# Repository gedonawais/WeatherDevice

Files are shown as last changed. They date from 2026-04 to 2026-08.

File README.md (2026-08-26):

# Weather Device - Raspberry Pi Zero 2W Setup Guide

This document explains how to set up the Raspberry Pi Zero 2W for the Weather Device project.

---

# 1. Install Raspberry Pi OS Lite (64 Bit) without Desktop

1. Download and install **Raspberry Pi OS Lite** using Raspberry Pi Imager.
2. Flash the OS to the SD card.
3. Before writing the image, configure:
   - Set username and password
   - Configure Wi-Fi (optional)

Boot the Raspberry Pi.

---

# 2. Configure Raspberry Pi

## 2.1 Enable Automatic Login

Open the Raspberry Pi configuration tool:

```bash
sudo raspi-config
```
Set System Date and Time and WLAN Country in the Localisation menu
Set Wireless LAN SSID and Password (for wifi)

Navigate to:
```
System Options
    → Auto Login
        → Console Autologin
```

Select console auto login.

This allows the Raspberry Pi to automatically log in after boot.

---

## 2.2 Disable sudo Password Requirement

Navigate to:
```
System Options
    → Admin Password
        → Disable
```

This allows scripts and services to execute sudo commands without requiring a password.

---

# 3. Configure Network

## 3.1 Connect to Wi-Fi

Open Raspberry Pi configuration:

```bash
sudo raspi-config
```

Navigate to:

```
System Options
    → Wireless LAN
```

Enter:

- Wi-Fi SSID
- Wi-Fi password

Reboot if required.

---

# 4. Install Required Software

## 4.1 Update Package List

Run:

```bash
sudo apt update
```

---

## 4.2 Install Git

Install Git:

```bash
sudo apt install git -y
```

Verify installation:

```bash
git --version
```

---

# 5. Download Weather Device Repository
If you wish to enable Wifi use the following commands

```bash
sudo systemctl enable NetworkManager.service
sudo systemctl start NetworkManager.service
sudo nmcli radio wifi on
```
Move to the home directory:

```bash
cd /home
```

Clone the repository:

```bash
sudo git clone <REPOSITORY_URL>
```

Example:

```bash
sudo git clone https://github.com/<username>/WeatherDevice.git
```

The project should now be available at:

```
/home/WeatherDevice
```

---

# 6. Configure Git Repository Permission

If Git shows a **"detected dubious ownership in repository"** error, run:

```bash
git config --global --add safe.directory /home/WeatherDevice
```

---

# 7. Deploy System Configuration

Run the configuration deployment script:

```bash
bash /home/WeatherDevice/Firmware/RPi/Installations/deploy_config.sh
```

This installs required system files, services, and configurations.

---

# 8. Restart Raspberry Pi

Reboot the device:

```bash
sudo reboot
```

Wait until the Raspberry Pi boots again.

---

# 9. Install Python Dependencies

Run the installation script:

```bash
bash /home/WeatherDevice/Firmware/RPi/Installations/install.sh
```

This installs all required libraries and dependencies.

---

# 10. Disable Wi-Fi (Optional)
Network Manager is already disabled so no need to run this
Disable Wi-Fi:

```bash
sudo nmcli radio wifi off
```

Check Wi-Fi status:

```bash
nmcli radio
```

---

# 11. Weather Service Management

## Start Weather Service

```bash
sudo systemctl start weather.service
```

---

## Enable Service at Boot

To automatically start the weather application after every reboot:

```bash
sudo systemctl enable weather.service
```

---

## Check Service Status

```bash
sudo systemctl status weather.service
```

---

## View Live Service Logs

To monitor real-time logs:

```bash
journalctl -u weather.service -f
```

---

## Restart Service if there are any issues in logs

After changing code:

```bash
sudo systemctl restart weather.service
```

---

# 12. Updating the Software

To update the Weather Device software:

```bash
sudo nmcli radio wifi on
cd /home/WeatherDevice
```

Download the latest changes:

```bash
sudo git pull
sudo nmcli radio wifi off
```

Restart the service:

```bash
sudo systemctl restart weather.service
```

---

# Setup Complete

The Raspberry Pi Zero 2W is now configured and ready to run the Weather Device application.

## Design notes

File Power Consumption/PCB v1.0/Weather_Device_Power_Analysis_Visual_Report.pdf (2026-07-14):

# Weather Device Power Analysis Report

Visual summary based on 24-hour measurements.

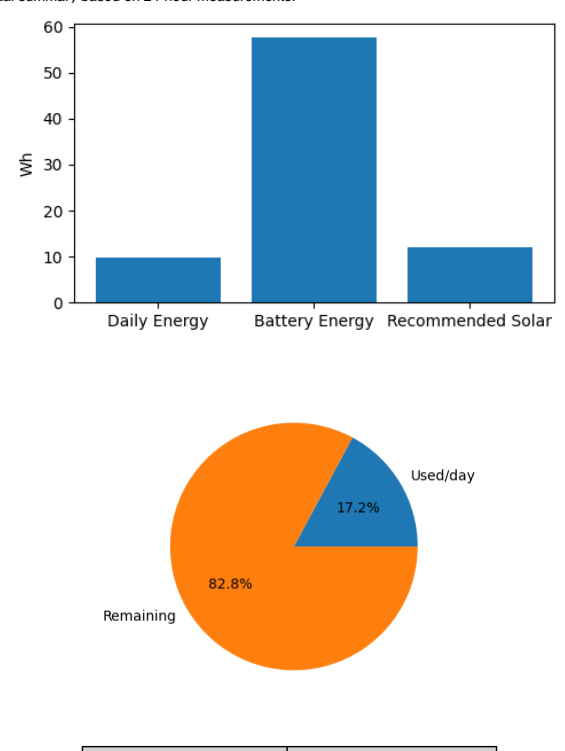
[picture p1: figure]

Metric | Value
Daily Energy | 9.896 Wh
Daily Charge | 842.3 mAh
Average Power | 0.412 W
Battery | 3S Li-ion 5200 mAh (57.7 Wh)
Runtime | ~5.8 days

Recommended Solar Harvest >=12 Wh/day

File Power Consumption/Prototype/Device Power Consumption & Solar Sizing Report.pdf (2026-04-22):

# Device Power Consumption & Solar Sizing Report (24h Analysis)

### 1. Daily Energy Consumption

Total: 7.613 Wh/day
Active: 7.333 Wh (~3.72 h) Sleep: 0.280 Wh (~20.26 h) Active dominates (~96.3% energy)

### 2. Power Profile

Active: ~1.97 W
Sleep: ~0.014 W (14 mW)

### 3. System Losses

Efficiency: 70%
Required: 10.9 Wh/day

### 4. Solar Sizing (Germany)

Sunny (5 PSH): 2.2 W
Average (3 PSH): 3.6 W
Cloudy (1.5 PSH): 7.3 W
Winter (1 PSH): 10.9 W

### 5. Recommendation

10–15 W solar panel
Battery: 15–25 Wh (2–3 days autonomy)

### 6. Conclusion

Works fine in theory. Winter decides reality.

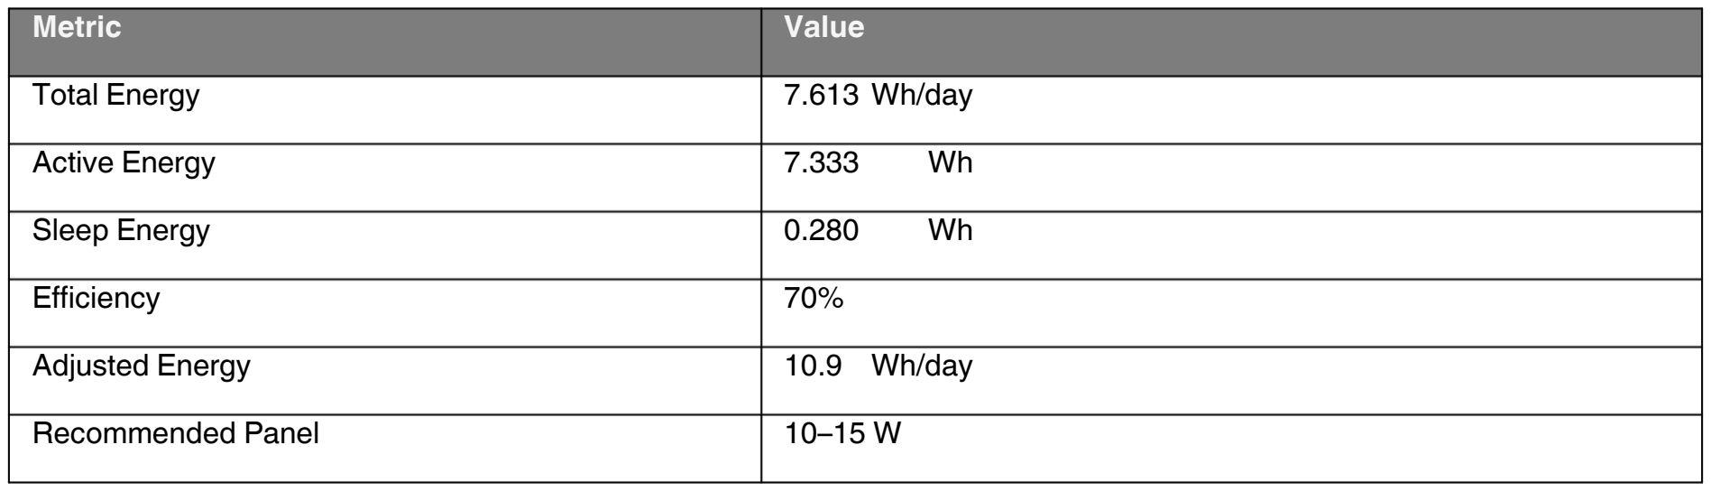
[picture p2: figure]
Metric; Total Energy; Active Energy; Sleep Energy; Efficiency; Adjusted Energy; Recommended Panel; Value; 7.613 Wh/day; 10.9 Wh/day

## consumption is 7.6Wh/day if we consider 70% efficiency then 10.9 or 11Wh/day 20W of solar panel will generate approx 17Wh/day during Bad Days 15W of solar panel will generate approx 12.75Wh/day during Bad Day

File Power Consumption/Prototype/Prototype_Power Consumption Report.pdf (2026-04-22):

# Device Power Consumption Report 24h

## Time(m) spent in each state:

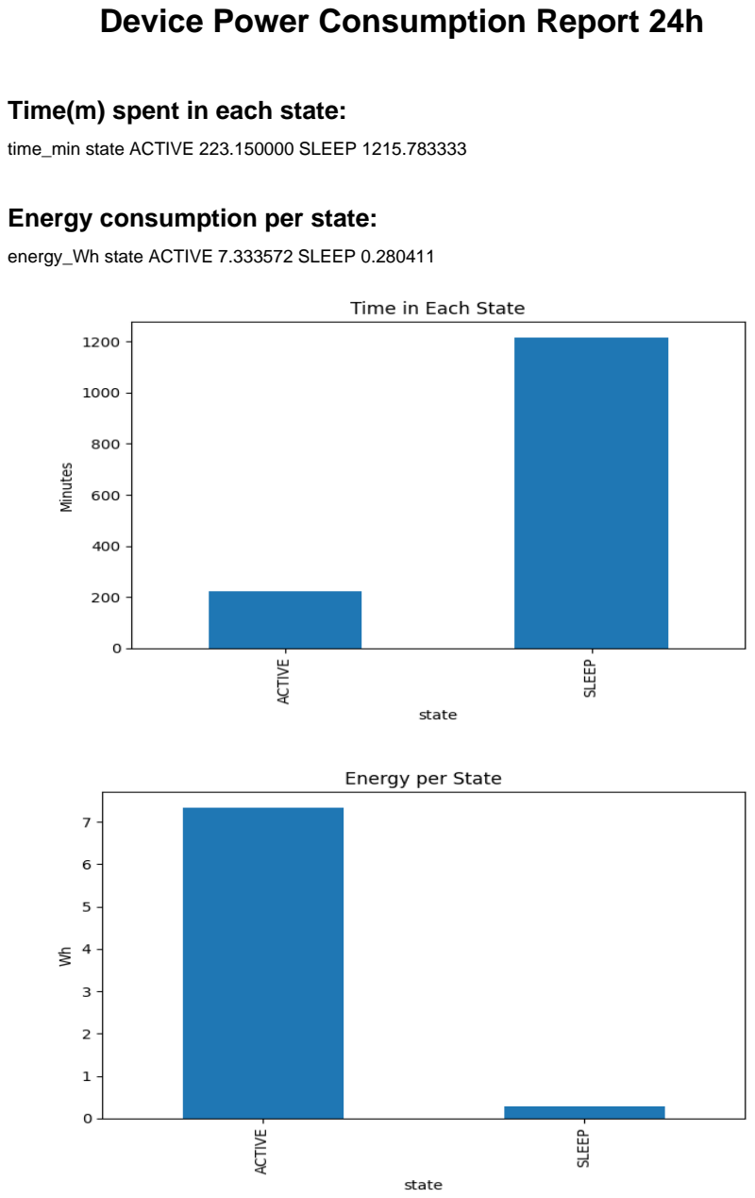
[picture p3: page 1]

time_min state ACTIVE 223.150000 SLEEP 1215.783333

## Energy consumption per state:

energy_Wh state ACTIVE 7.333572 SLEEP 0.280411

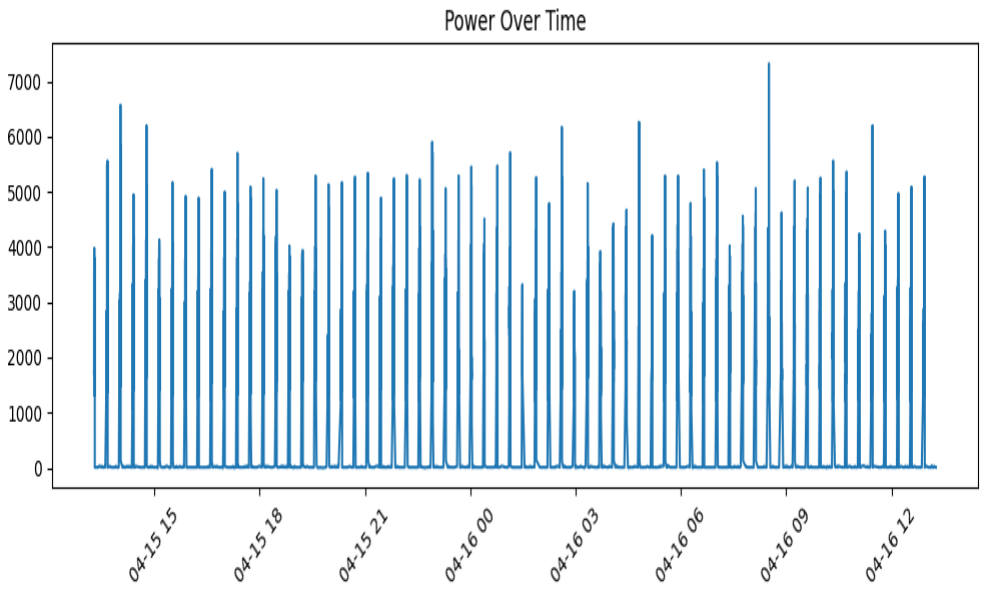
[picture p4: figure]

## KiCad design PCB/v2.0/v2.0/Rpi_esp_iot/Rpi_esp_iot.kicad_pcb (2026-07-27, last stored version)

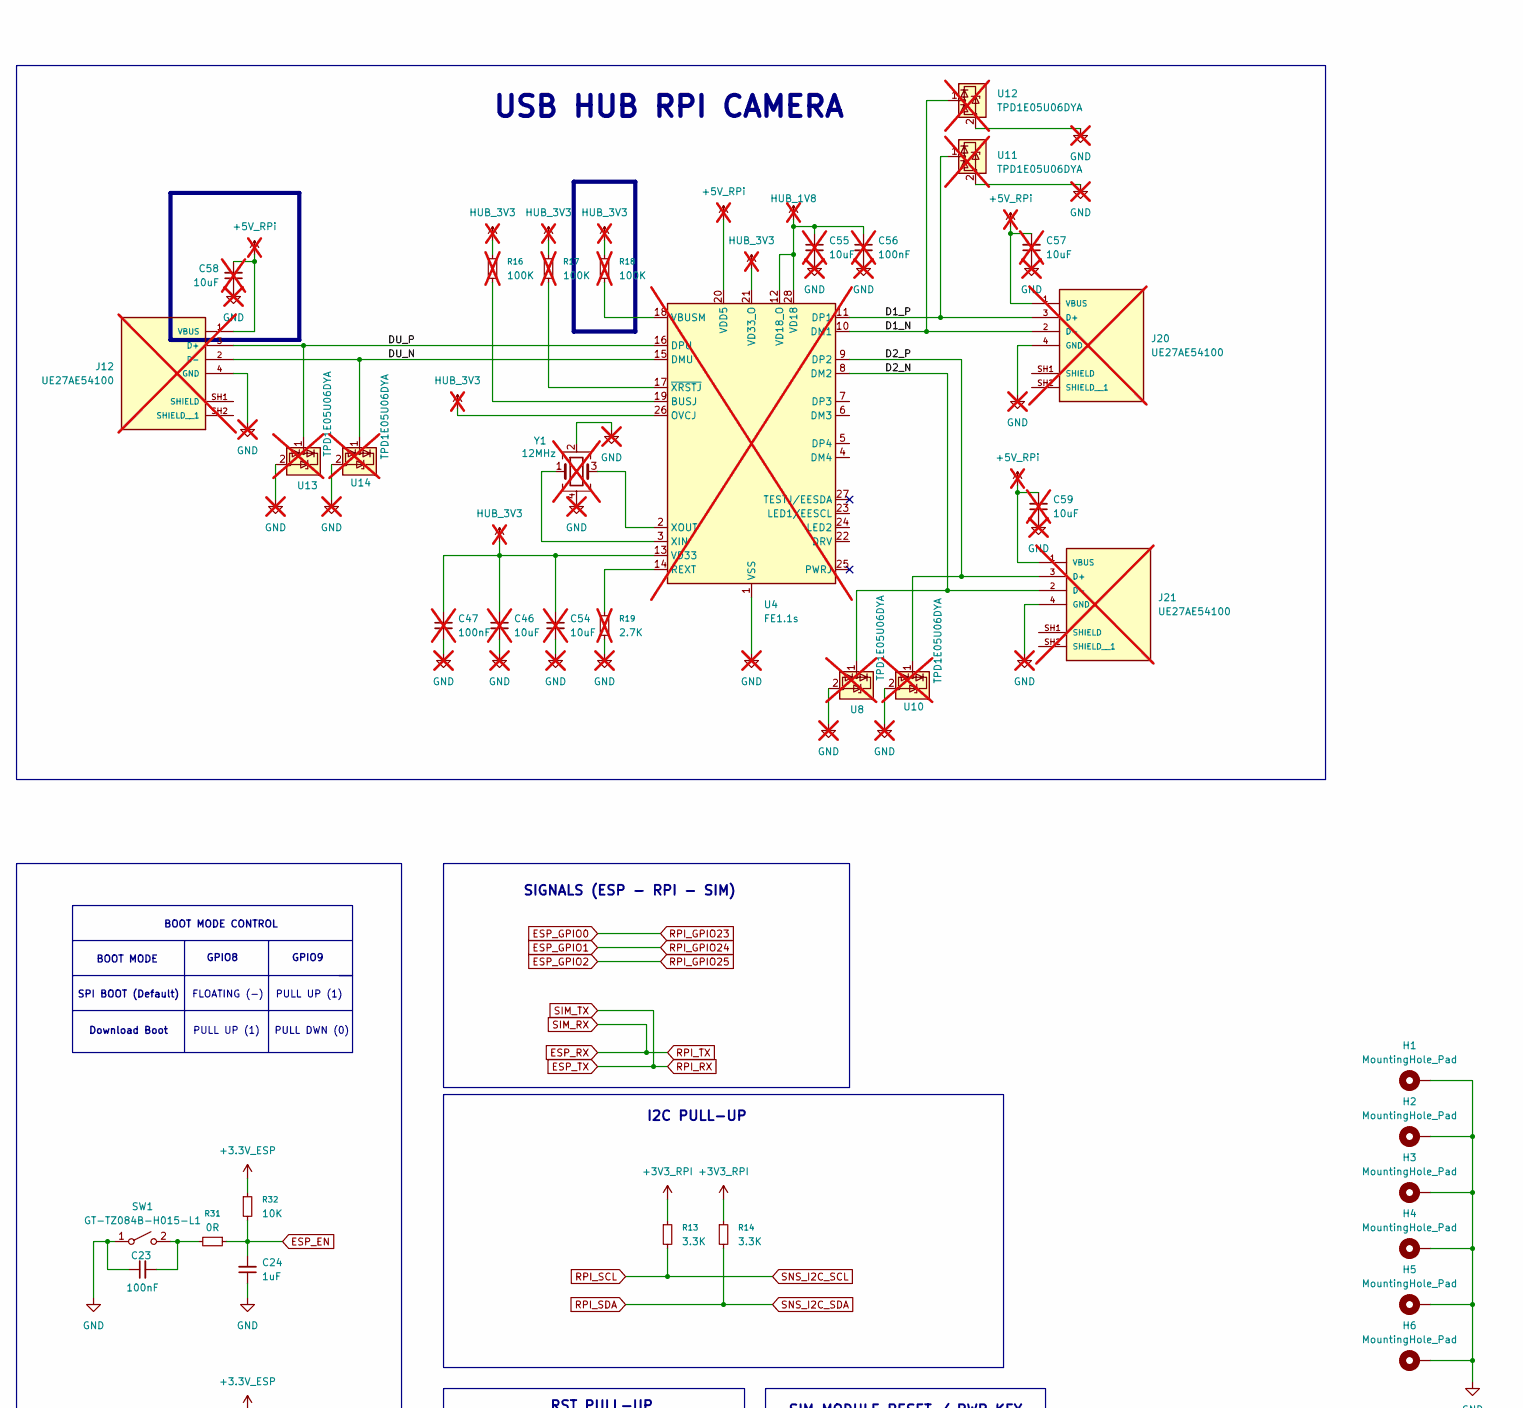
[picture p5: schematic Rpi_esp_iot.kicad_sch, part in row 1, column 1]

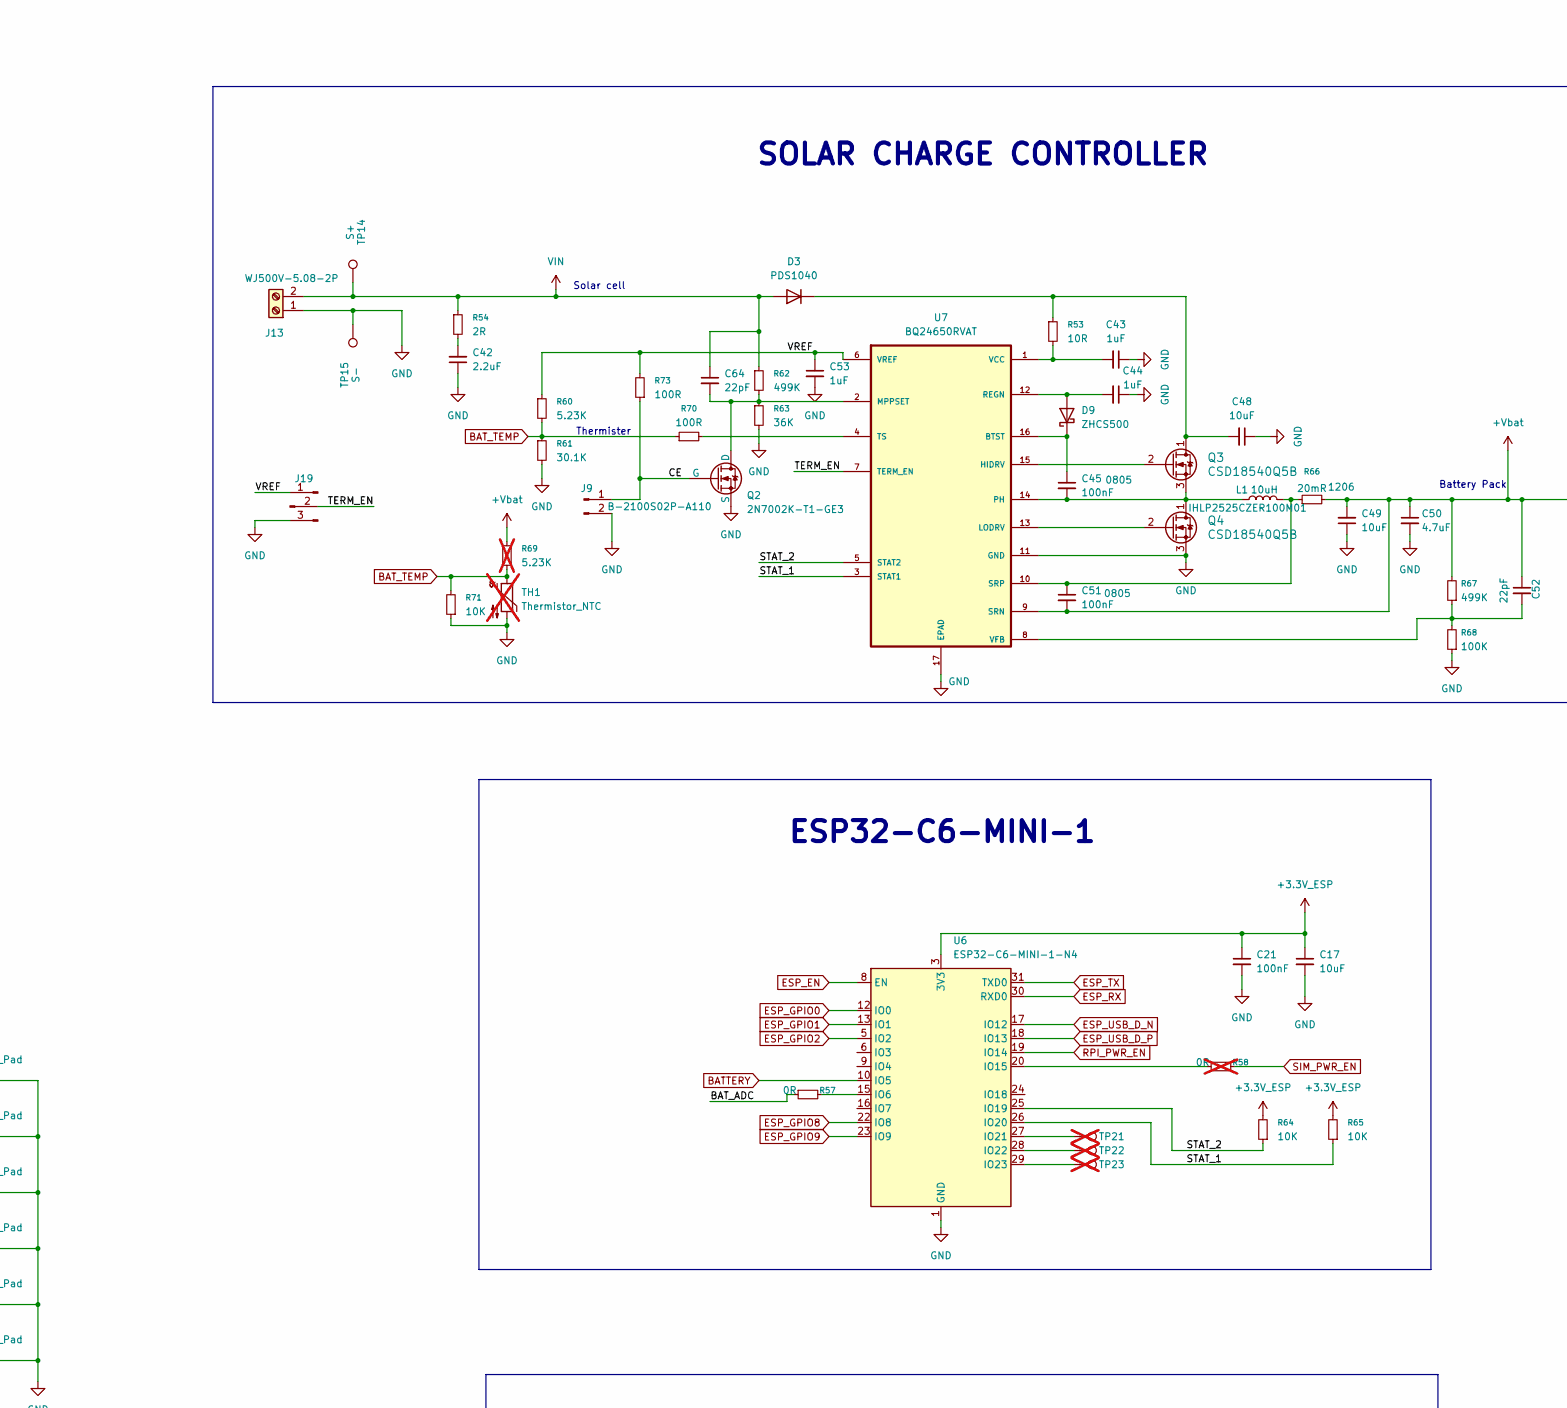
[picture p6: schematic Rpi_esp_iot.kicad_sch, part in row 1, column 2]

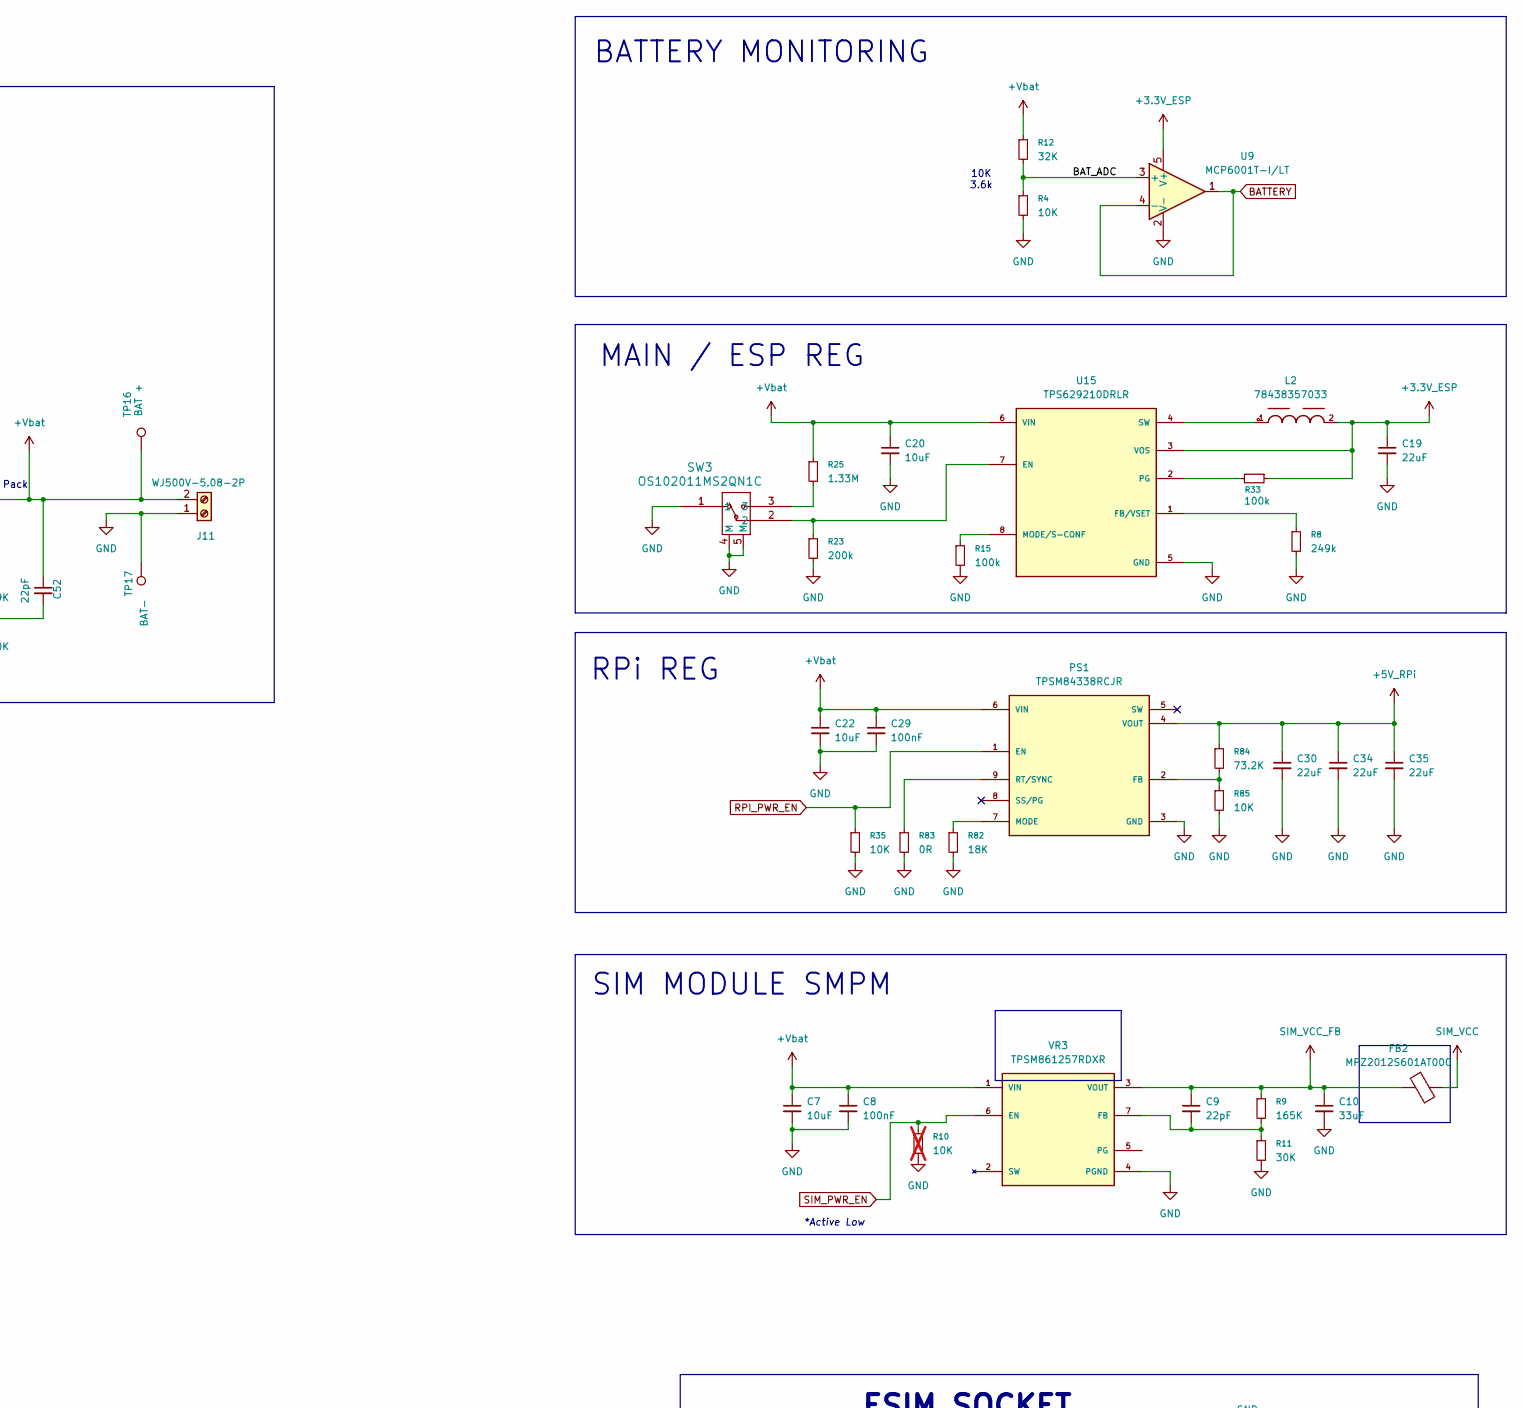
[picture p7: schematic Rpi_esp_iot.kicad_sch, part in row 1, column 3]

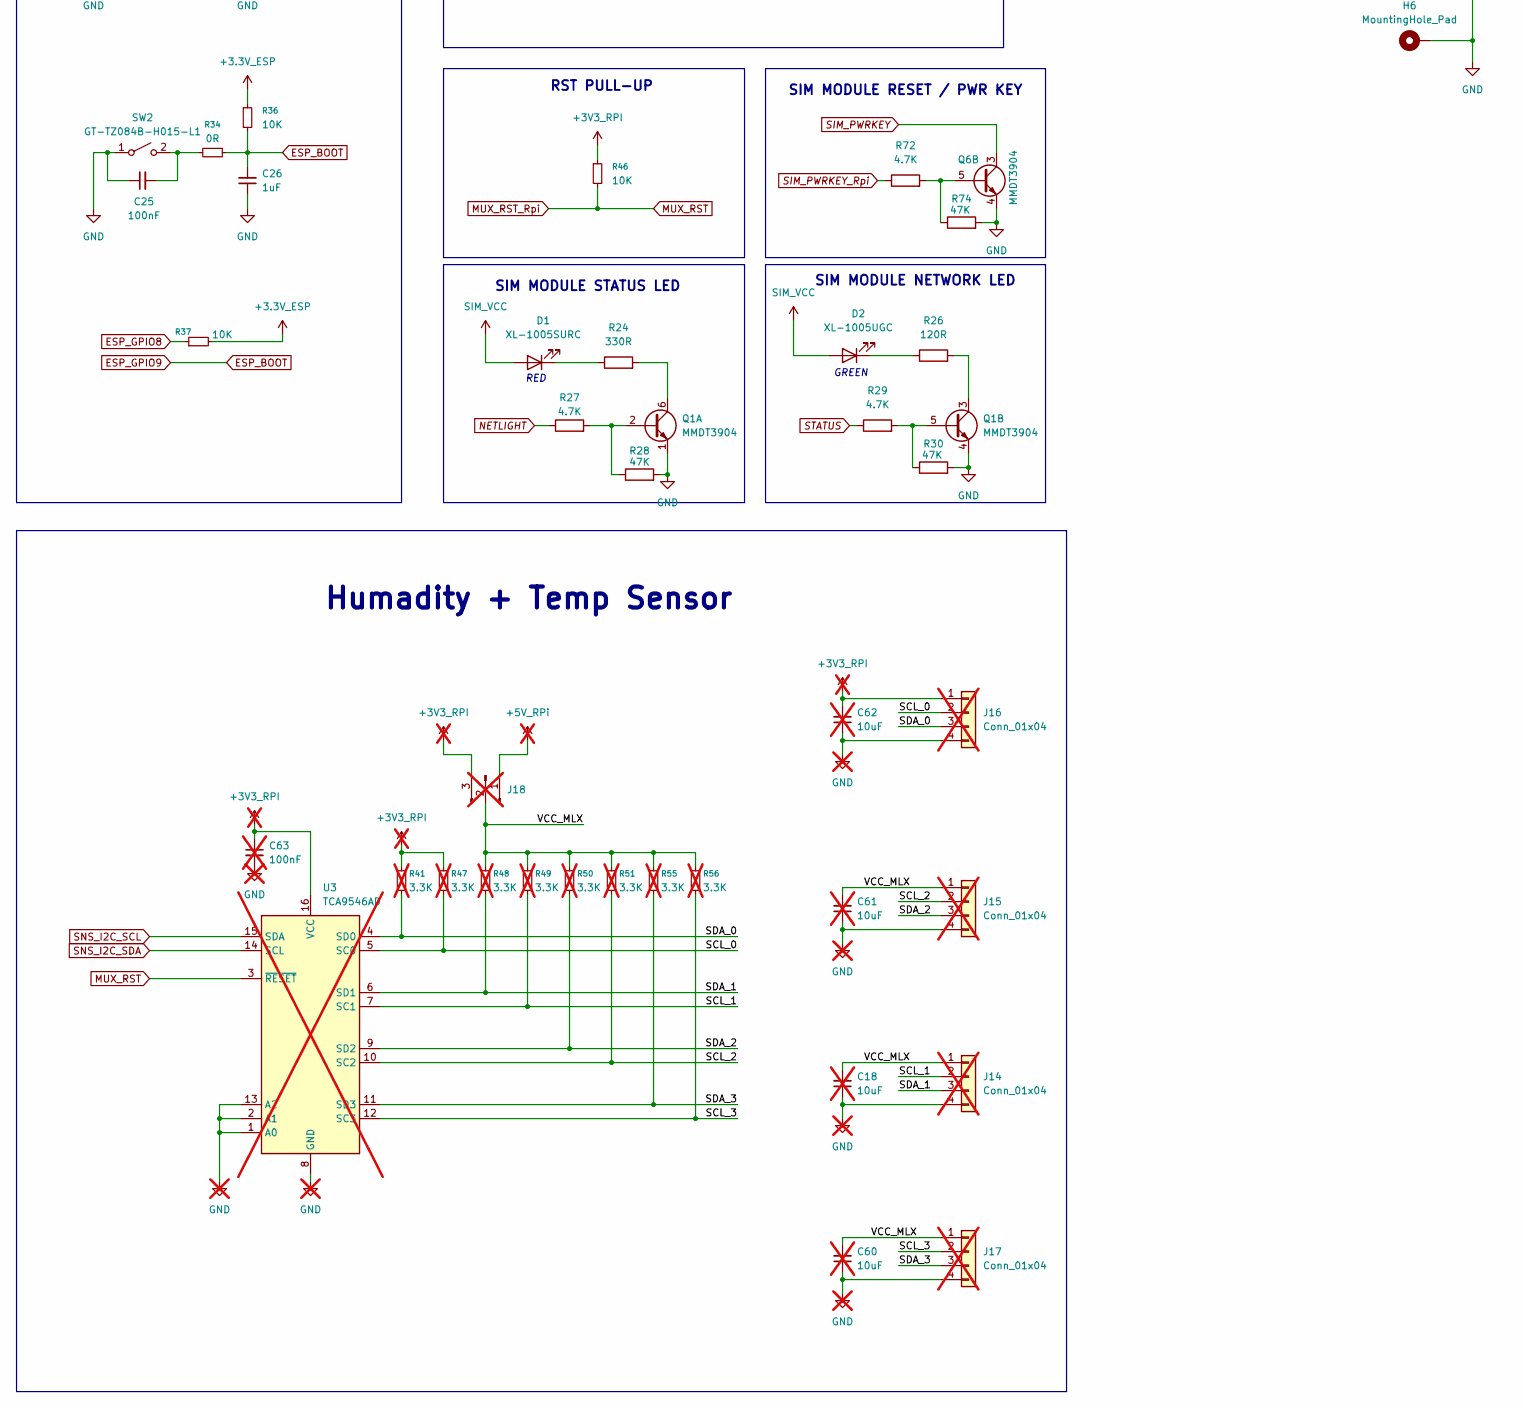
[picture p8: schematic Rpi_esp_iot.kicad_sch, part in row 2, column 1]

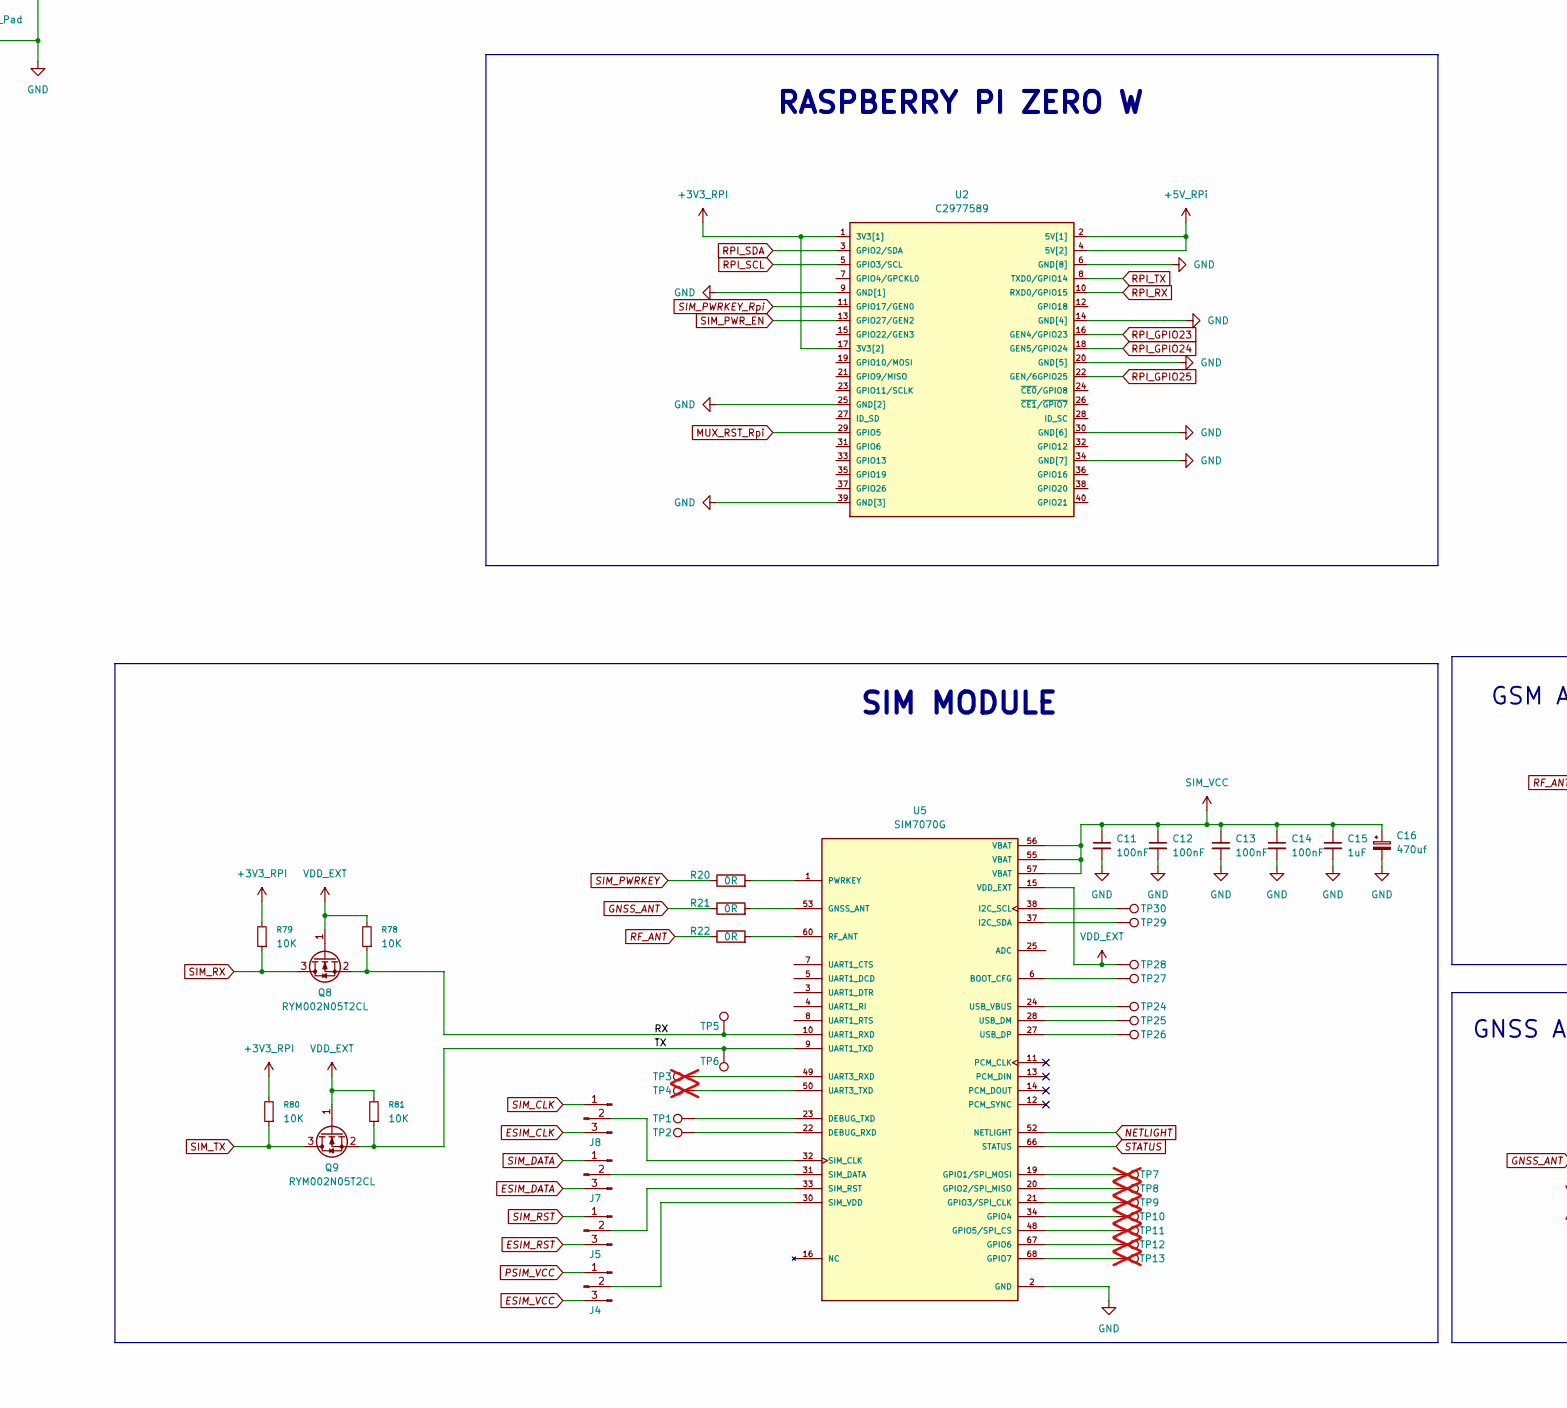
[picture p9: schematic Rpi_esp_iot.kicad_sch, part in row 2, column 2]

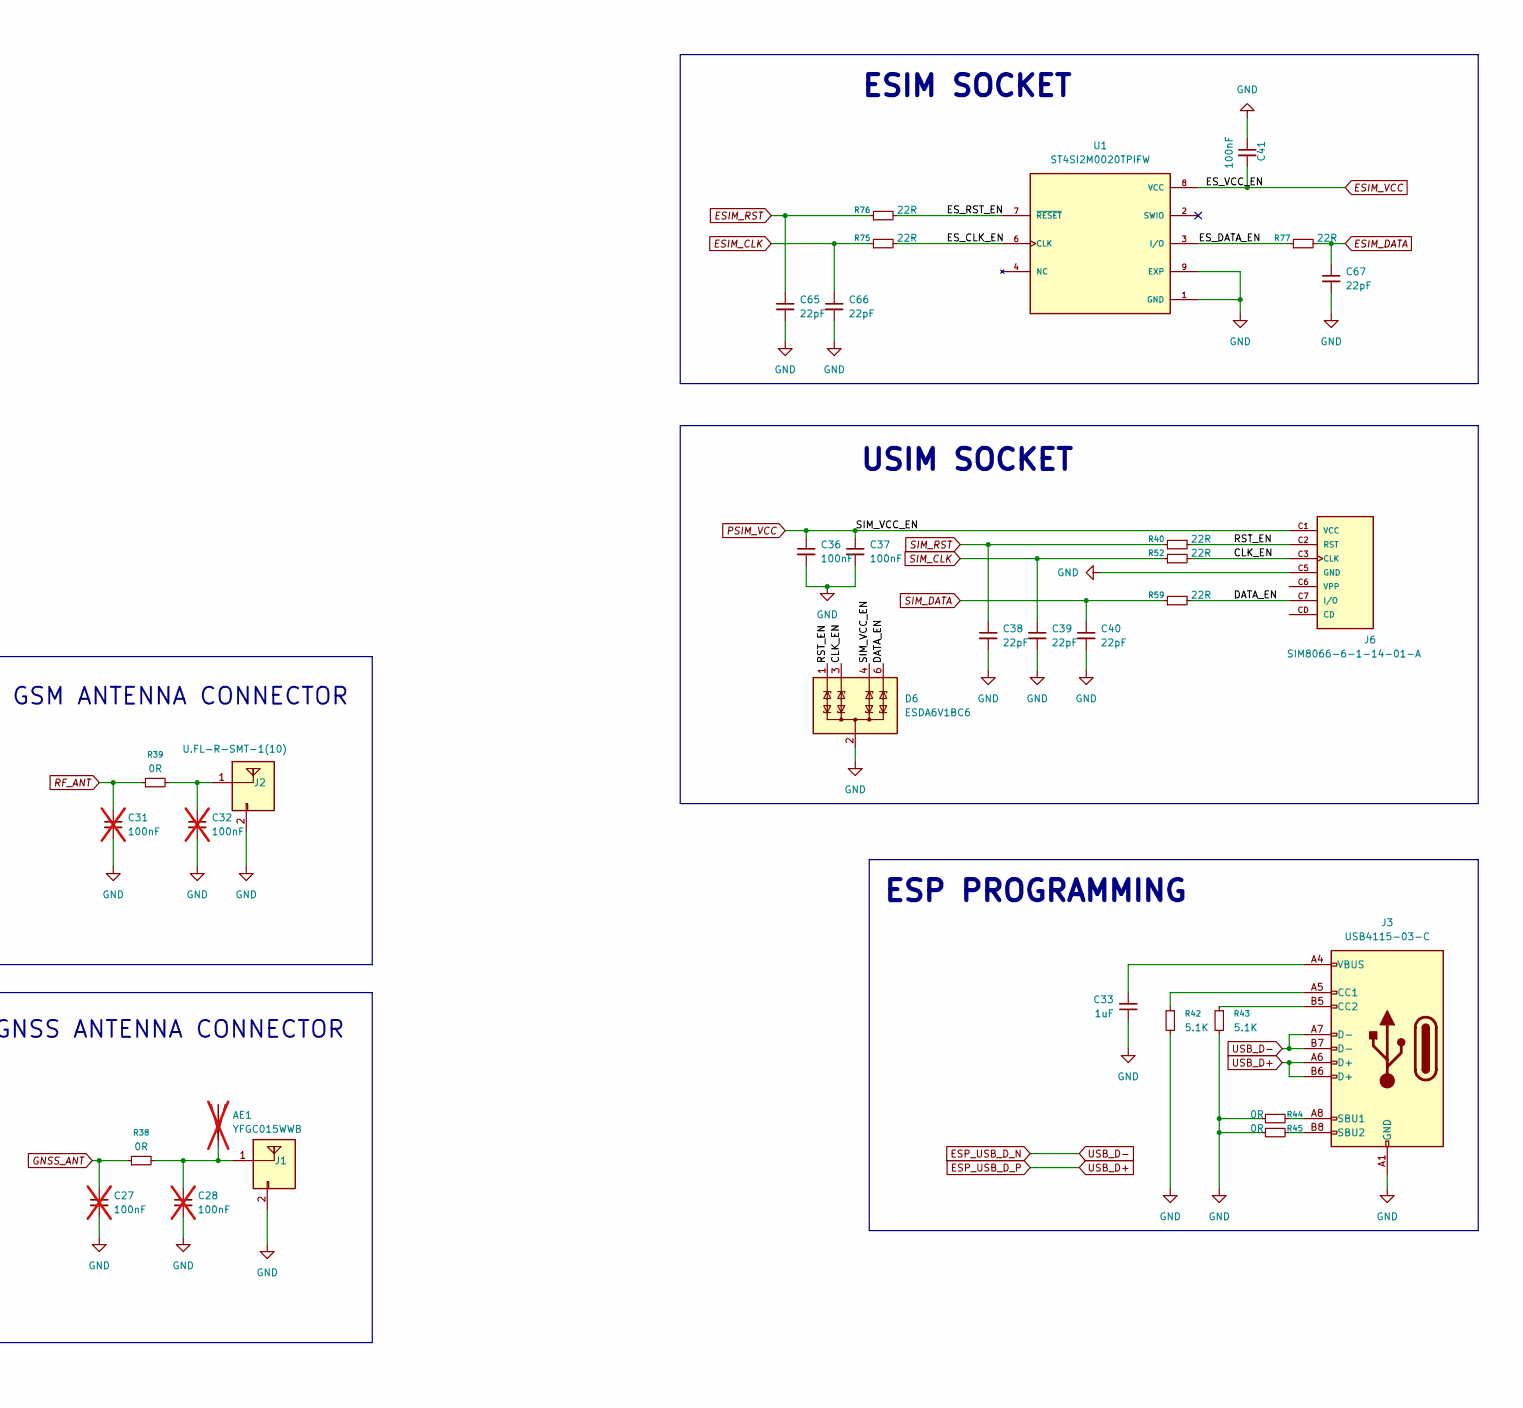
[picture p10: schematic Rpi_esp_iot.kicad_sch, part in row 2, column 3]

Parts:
AE1: YFGC015WWB; not fitted
C7, C17, C22: 10uF; C_1206_3216Metric; Manufacturer Part Number CL05A106MP5NUNC
C8, C11, C12, C13, C14, C21, C23, C25, C36, C37, C41: 100nF; C_0402_1005Metric; Manufacturer Part Number CC0402KRX7R7BB104
C9: 22pF; C_0402_1005Metric; Manufacturer Part Number GRM1555C1H220JA01D
C10: 33uF; C_1206_3216Metric; Manufacturer Part Number CL05C330JB5NNNC
C15, C24, C26, C33: 1uF; C_0402_1005Metric; Manufacturer Part Number CL05A105KP5NNNC
C16: 470uf; CP_EIA-7343-15_Kemet-W_HandSolder; Manufacturer Part Number TAJD477K006RNJ
C18, C57, C58, C59, C60, C61, C62: 10uF; C_1210_3225Metric_Pad1.33x2.70mm_HandSolder; Manufacturer Part Number CC1210KKX7R9BB106; not fitted
C19, C30, C34, C35: 22uF; C_1206_3216Metric; Manufacturer Part Number CL05C330JB5NNNC
C20: 10uF; C_1206_3216Metric; Manufacturer Part Number CL05C330JB5NNNC
C27, C28, C31, C32, C47, C56, C63: 100nF; C_0402_1005Metric; Manufacturer Part Number CC0402KRX7R7BB104; not fitted
C29: 100nF; C_0805_2012Metric; Manufacturer Part Number CC0402KRX7R7BB104
C38, C39, C40, C65, C66, C67: 22pF; C_0402_1005Metric; Manufacturer Part Number CL05A226MQ5QUNC
C42: 2.2uF; C_1210_3225Metric_Pad1.33x2.70mm_HandSolder; Manufacturer Part Number C1210C225K1RACAUTO
C43, C44, C53: 1uF; C_0805_2012Metric_Pad1.18x1.45mm_HandSolder; Manufacturer Part Number C0805C105K5RACAUTO
C45, C51: 100nF; R_0805_2012Metric; Manufacturer Part Number CC0805KRX7R9BB104
C46, C54, C55: 10uF; C_0402_1005Metric; Manufacturer Part Number CL05A106MP5NUNC; not fitted
C48, C49: 10uF; C_1210_3225Metric_Pad1.33x2.70mm_HandSolder; Manufacturer Part Number CC1210KKX7R9BB106
C50: 4.7uF; C_1210_3225Metric_Pad1.33x2.70mm_HandSolder; Manufacturer Part Number CL32B475KBUYNNE
C52, C64: 22pF; C_0603_1608Metric_Pad1.08x0.95mm_HandSolder; Manufacturer Part Number C0603C220K5RACAUTO
D1: XL-1005SURC; LED_0402_1005Metric_Pad0.77x0.64mm_HandSolder; Manufacturer Part Number XL-1005SURC
D2: XL-1005UGC; LED_0402_1005Metric_Pad0.77x0.64mm_HandSolder; Manufacturer Part Number XL-1005UGC
D3: PDS1040; D_PowerDI-5; Manufacturer Part Number PDS1040-13
D6: ESDA6V1BC6; SOT-23-6_Handsoldering; Manufacturer Part Number ESDA6V1BC6
D9: ZHCS500; SOT-23-3; Manufacturer Part Number ZHCS500TA
FB2: MPZ2012S601AT000; C_0805_2012Metric; Manufacturer Part Number MPZ2012S601AT000
H1, H2, H3, H4, H5, H6: MountingHole_Pad; MountingHole_3.2mm_M3_DIN965_Pad
J1, J2: U.FL-R-SMT-1(10); U.FL_Hirose_U.FL-R-SMT-1_Vertical; Manufacturer Part Number U.FL-R-SMT-1(80)
J3: USB4115-03-C; USB4115-03-C_GCT; Manufacturer Part Number USB4115-03-C
J4, J5, J7, J8, J19: MTP220-1103S1; PinHeader_1x03_P2.00mm_Vertical
J6: SIM8066-6-1-14-01-A; GCT_SIM8066-6-1-14-01-A_REVA; PARTREV REVA; DigiKey_Part_Number 2073-SIM8066-6-1-14-01-ACT-ND
J9: B-2100S02P-A110; PinSocket_1x02_P2.54mm_Vertical
J11, J13: WJ500V-5.08-2P; TerminalBlock_bornier-2_P5.08mm
J12, J20, J21: UE27AE54100; AMPHENOL_UE27AE54100; PARTREV G; not fitted
J14, J15, J16, J17: Conn_01x04; JST_PH_S4B-PH-K_1x04_P2.00mm_Horizontal; not fitted
J18: MTP220-1103S1; PinHeader_1x03_P2.00mm_Vertical; not fitted
L1: IHLP2525CZER100M01; L_Vishay_IHLP-2525; Manufacturer Part Number 10uH
L2: 78438357033; WE-MAIA_4030
PS1: TPSM84338RCJR; CONV_TPSM84338RCJR; PARTREV November 2024
Q1, Q6: MMDT3904; SOT-363_SC-70-6; Manufacturer Part Number MMDT3904
Q2: 2N7002K-T1-GE3; SOT-23_Handsoldering; Manufacturer Part Number 2N7002K-T1-GE3
Q3, Q4: CSD18540Q5B; Manufacturer Part Number CSD18540Q5B
Q8, Q9: RYM002N05T2CL; SOT-723
R4, R32, R35, R36, R37, R46, R64, R65, R71, R78, R79, R80, R81: 10K; R_0402_1005Metric; Manufacturer Part Number RC0402FR-0710KL
R8: 249k; R_0402_1005Metric; Manufacturer Part Number RC0402FR-0710KL
R9: 165K; R_0402_1005Metric; Manufacturer Part Number RK73H1ET1653F-CN
R10: 10K; R_0402_1005Metric; Manufacturer Part Number RC0402FR-0710KL; not fitted
R11: 30K; R_0402_1005Metric; Manufacturer Part Number RC0402FR-0730KL
R12: 32K; R_0402_1005Metric; Manufacturer Part Number TNPW040232K0BEED
R13, R14: 3.3K; R_0402_1005Metric; Manufacturer Part Number RC0402FR-0710KL
R15, R33: 100k; R_0402_1005Metric; Manufacturer Part Number RC0402FR-0710KL
R16, R17, R18: 100K; R_0402_1005Metric; Manufacturer Part Number RC0402FR-0710KL; not fitted
R19: 2.7K; R_0402_1005Metric; Manufacturer Part Number RC0402FR-0710KL; not fitted
R20, R21, R22, R31, R34, R38, R39, R44, R45, R57: 0R; R_0402_1005Metric; Manufacturer Part Number RC0402FR-070RL
R23: 200k; R_0402_1005Metric; Manufacturer Part Number RC0402FR-0710KL
R24: 330R; R_0402_1005Metric; Manufacturer Part Number RC0402FR-07330RL
R25: 1.33M; R_0402_1005Metric; Manufacturer Part Number RC0402FR-0710KL
R26: 120R; R_0402_1005Metric; Manufacturer Part Number RC0402FR-07120RL
R27, R29, R72: 4.7K; R_0402_1005Metric; Manufacturer Part Number RC0402FR-074K7L
R28, R30, R74: 47K; R_0402_1005Metric; Manufacturer Part Number RC0402FR-0747KL
R40, R52, R59, R75, R76, R77: 22R; R_0402_1005Metric; Manufacturer Part Number RC0402FR-070RL
R41, R47, R48, R49, R50, R51, R55, R56: 3.3K; R_0402_1005Metric; Manufacturer Part Number RC0402FR-0710KL; not fitted
R42, R43: 5.1K; R_0402_1005Metric; Manufacturer Part Number RC0402FR-0710KL
R53: 10R; R_1206_3216Metric_Pad1.30x1.75mm_HandSolder; Manufacturer Part Number RC1206FR-0710RL
R54: 2R; R_2512_6332Metric_Pad1.40x3.35mm_HandSolder; Manufacturer Part Number MFCR2512F2R00Q9R
R58: 0R; R_0402_1005Metric; Manufacturer Part Number RC0402FR-070RL; not fitted
R60: 5.23K; R_0402_1005Metric; Manufacturer Part Number ARG02BTC5231
R61: 30.1K; R_0402_1005Metric; Manufacturer Part Number 0402WGF3012TCE
R62, R67: 499K; R_0402_1005Metric; Manufacturer Part Number RC0402FR-07499KL
R63: 36K; R_0402_1005Metric; Manufacturer Part Number FRC0402F3602TS
R66: 20mR; R_1206_3216Metric_Pad1.30x1.75mm_HandSolder; Manufacturer Part Number JER1206F1R020
R68: 100K; R_0402_1005Metric; Manufacturer Part Number RC0402FR-07100KL
R69: 5.23K; R_0402_1005Metric; Manufacturer Part Number ARG02BTC5231; not fitted
R70, R73: 100R; R_0402_1005Metric; Manufacturer Part Number RC0402FR-0710KL
R82: 18K; R_0402_1005Metric; Manufacturer Part Number RC0402FR-0710KL
R83: 0R; R_0402_1005Metric; Manufacturer Part Number RC0402FR-0710KL
R84: 73.2K; R_0402_1005Metric; Manufacturer Part Number RC0402FR-07220KL
R85: 10K; R_0402_1005Metric; Manufacturer Part Number RC0402FR-0730KL
SW1, SW2: GT-TZ084B-H015-L1; SW_SPST_SKQG_WithStem; Manufacturer Part Number GT-TZ084B-H015-L1
SW3: OS102011MS2QN1C; SW-TH_OS102011MS2QN1
TH1: Thermistor_NTC; R_0402_1005Metric_Pad0.72x0.64mm_HandSolder; Manufacturer Part Number FNTC0402X103F3380FB; not fitted
TP1, TP2, TP5, TP6, TP24, TP25, TP26, TP27, TP28, TP29, TP30: TestPoint; TestPoint_Pad_D1.5mm
TP3, TP4, TP7, TP8, TP9, TP10, TP11, TP12, TP13, TP21, TP22, TP23: TestPoint; TestPoint_Pad_2.0x2.0mm; not fitted
TP14: S+; TestPoint_Pad_2.0x2.0mm
TP15: S-; TestPoint_Pad_2.0x2.0mm
TP16: BAT +; TestPoint_Pad_2.0x2.0mm
TP17: BAT-; TestPoint_Pad_2.0x2.0mm
U1: ST4SI2M0020TPIFW; SON127P500X600X100-9N; PARTREV 5
U2: C2977589; Raspberry_Pi_Zero_Socketed_THT_FaceDown_MountingHoles; Manufacturer Part Number RASPBERRYPI-ZERO
U3: TCA9546AD; SOIC-16_3.9x9.9mm_P1.27mm; not fitted
U4: FE1.1s; SSOP-28_3.9x9.9mm_P0.635mm; not fitted
U5: SIM7070G; MODULE_SIM7070G; PARTREV V1.03; DigiKey_Part_Number 3781-SIM7070G-ND
U6: ESP32-C6-MINI-1-N4; ESP32-C6-MINI-1; Manufacturer Part Number ESP32-C6-MINI-1-N4
U7: BQ24650RVAT; QFN50P350X350X100-17N; Manufacturer Part Number BQ24650RVAT; DigiKey_Part_Number 296-27699-1-ND
U8, U10, U11, U12, U13, U14: TPD1E05U06DYA; D_SOD-523; not fitted
U9: MCP6001T-I/LT; SOT-353_SC-70-5
U15: TPS629210DRLR; SOT50P160X60-8N; PARTREV B; DigiKey_Part_Number 296-TPS629210DRLRCT-ND
VR3: TPSM861257RDXR; VREG_TPSM863252RDXR; PARTREV B; DigiKey_Part_Number 296-TPSM861257RDXRCT-ND
Y1: 12MHz; Crystal_SMD_3225-4Pin_3.2x2.5mm; not fitted

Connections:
+3.3V_ESP: C17.1, C19.1, C21.1, L2.2, R32.1, R33.1, R36.1, R37.2, R64.2, R65.2, U6.3 (3V3), U9.5 (V+), U15.3 (VOS)
+3V3_RPI: C62.2, C63.1, J16.1, J18.3, R13.1, R14.1, R41.1, R46.1, R47.1, R79.2, R80.2, U2.1 (3V3[1]), U2.17 (3V3[2]), U3.16 (VCC)
+5V_RPi: C30.1, C34.1, C35.1, C57.2, C58.2, C59.2, J12.1 (VBUS), J18.1, J20.1 (VBUS), J21.1 (VBUS), PS1.4 (VOUT), R84.1, U2.2 (5V[1]), U2.4 (5V[2]), U4.20 (VDD5)
+Vbat: C7.1, C8.1, C20.1, C22.1, C29.1, C49.2, C50.1, C51.2, C52.1, J11.2, PS1.6 (VIN), R12.1, R25.1, R66.2, R67.2, R69.1, TP16.1 (1_1), U7.9 (SRN), U15.6 (VIN), VR3.1 (VIN)
/BAT_ADC: R4.1, R12.2, R57.1, U9.3 (+)
/CE: J9.1, Q2.2 (G), R73.1
/CLK_EN: D6.3 (TVS2), J6.C3 (CLK), R52.2
/D1_N: J20.2 (D-), U4.10 (DM1), U12.1 (I/O)
/D1_P: J20.3 (D+), U4.11 (DP1), U11.1 (I/O)
/D2_N: J21.2 (D-), U4.8 (DM2), U8.1 (I/O)
/D2_P: J21.3 (D+), U4.9 (DP2), U10.1 (I/O)
/DATA_EN: D6.6 (TVS4), J6.C7 (I/O), R59.2
/DU_N: J12.2 (D-), U4.15 (DMU), U14.1 (I/O)
/DU_P: J12.3 (D+), U4.16 (DPU), U13.1 (I/O)
/ES_CLK_EN: R75.2, U1.6 (CLK)
/ES_DATA_EN: R77.1, U1.3 (I/O)
/ES_RST_EN: R76.2, U1.7 (~RESET)
/RST_EN: D6.1 (TVS1), J6.C2 (RST), R40.2
/RX: Q8.2 (S), R78.1, TP5.1 (1_1), U5.10 (UART1_RXD)
/SCL_0: J16.2, R47.2, U3.5 (SC0)
/SCL_1: J14.2, R49.2, U3.7 (SC1)
/SCL_2: J15.2, R51.2, U3.10 (SC2)
/SCL_3: J17.2, R56.2, U3.12 (SC3)
/SDA_0: J16.3, R41.2, U3.4 (SD0)
/SDA_1: J14.3, R48.2, U3.6 (SD1)
/SDA_2: J15.3, R50.2, U3.9 (SD2)
/SDA_3: J17.3, R55.2, U3.11 (SD3)
/STAT_1: R65.1, U6.26 (IO20), U7.3 (STAT1)
/STAT_2: R64.1, U6.25 (IO19), U7.5 (STAT2)
/TERM_EN: J19.2, U7.7 (TERM_EN)
/TX: Q9.2 (S), R81.1, TP6.1 (1_1), U5.9 (UART1_TXD)
/VCC_MLX: C18.2, C60.2, C61.2, J14.1, J15.1, J17.1, J18.2, R48.1, R49.1, R50.1, R51.1, R55.1, R56.1
/VREF: C53.1, J19.1, R60.1, R73.2, U7.6 (VREF)
BATTERY: U6.10 (IO5), U9.1, U9.4 (-)
BAT_TEMP: R60.2, R61.1, R69.2, R70.1, R71.2, TH1.1
ESIM_CLK: C66.1, J8.3, R75.1
ESIM_DATA: C67.1, J7.3, R77.2
ESIM_RST: C65.1, J5.3, R76.1
ESIM_VCC: C41.2, J4.3, U1.8 (VCC)
ESP_BOOT: C26.2, R34.1, R36.2, U6.23 (IO9)
ESP_EN: C24.2, R31.1, R32.2, U6.8 (EN)
ESP_GPIO0: U2.16 (GEN4/GPIO23), U6.12 (IO0)
ESP_GPIO1: U2.18 (GEN5/GPIO24), U6.13 (IO1)
ESP_GPIO2: U2.22 (GEN/6GPIO25), U6.5 (IO2)
ESP_GPIO8: R37.1, U6.22 (IO8)
ESP_RX: Q8.3 (D), R79.1, U2.8 (TXD0/GPIO14), U6.30 (RXD0)
ESP_TX: Q9.3 (D), R80.1, U2.10 (RXD0/GPIO15), U6.31 (TXD0)
ESP_USB_D_N: J3.A7 (D-), J3.B7 (D-), U6.17 (IO12)
ESP_USB_D_P: J3.A6 (D+), J3.B6 (D+), U6.18 (IO13)
GND: C7.2, C8.2, C10.2, C11.2, C12.2, C13.2, C14.2, C15.2, C16.2, C17.2, C18.1, C19.2, C20.2, C21.2, C22.2, C23.1, C24.1, C25.1, C26.1, C27.2, C28.2, C29.2, C30.2, C31.2, C32.2, C33.1, C34.2, C35.2, C36.2, C37.2, C38.2, C39.2, C40.2, C41.1, C42.1, C43.1, C44.1, C46.2, C47.2, C48.1, C49.1, C50.2, C53.2, C54.2, C55.2, C56.2, C57.1, C58.1, C59.1, C60.1, C61.1, C62.1, C63.2, C65.2, C66.2, C67.2, D6.2 (COM), D6.5 (COM), H1.1 (1_1), H2.1 (1_1), H3.1 (1_1), H4.1 (1_1), H5.1 (1_1), H6.1 (1_1), J1.2, J2.2, J3.A1 (GND), J3.A12 (GND), J3.B1 (GND), J3.B12 (GND), J6.C5 (GND), J6.G1 (GND), J6.G2 (GND), J6.G3 (GND), J6.G4 (GND), J9.2, J11.1, J12.4 (GND), J13.1, J14.4, J15.4, J16.4, J17.4, J19.3, J20.4 (GND), J21.4 (GND), PS1.3 (GND), Q1.1 (E1)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
GNSS_ANT: C27.1, R21.1, R38.1
HUB_1V8: C55.1, C56.1, U4.12 (VD18_O), U4.28 (VD18)
HUB_3V3: C46.1, C47.1, C54.1, R16.1, R17.1, R18.1, U4.13 (VD33), U4.21 (VD33_O), U4.26 (OVCJ)
MUX_RST: R46.2, U2.29 (GPIO5), U3.3 (~RESET)
NETLIGHT: R27.1, U5.52 (NETLIGHT)
unnamed: C33.2, J3.A4 (VBUS), J3.A9 (VBUS), J3.B4 (VBUS), J3.B9 (VBUS)
unnamed: C42.2, R54.2
unnamed: D1.1 (K), R24.1
unnamed: D2.1 (K), R26.1
unnamed: C48.2, D3.1 (K), Q3.1, R53.1
unnamed: C44.2, D9.3 (A), U7.12 (REGN)
unnamed: C45.1, D9.1 (K), U7.16 (BTST)
unnamed: AE1.1, C28.1, J1.1, R38.2
unnamed: C32.1, J2.1, R39.2
unnamed: J3.A5 (CC1), R42.1
unnamed: J3.B5 (CC2), R43.1
unnamed: J3.A8 (SBU1), R44.2
unnamed: J3.B8 (SBU2), R45.2
unnamed: J4.2, U5.30 (SIM_VDD)
unnamed: J5.2, U5.33 (SIM_RST)
unnamed: J7.2, U5.31 (SIM_DATA)
unnamed: J8.2, U5.32 (SIM_CLK)
unnamed: PS1.2 (FB), R84.2, R85.1
unnamed: PS1.7 (MODE), R82.1
unnamed: PS1.9 (RT/SYNC), R83.1
unnamed: Q1.2 (B1), R27.2, R28.1
unnamed: Q1.6 (C1), R24.2
unnamed: Q1.5 (B2), R29.2, R30.1
unnamed: Q1.3 (C2), R26.2
unnamed: C64.2, Q2.1 (D), R62.2, R63.1, U7.2 (MPPSET)
unnamed: Q6.5 (B2), R72.2, R74.1
unnamed: R25.2, SW3.3
unnamed: C23.2, R31.2, SW1.2 (B)
unnamed: C25.2, R34.2, SW2.2 (B)
unnamed: R16.2, U4.19 (BUSJ)
unnamed: R19.1, U4.14 (REXT)
unnamed: R18.2, U4.18 (VBUSM)
unnamed: U4.3 (XIN), Y1.1
unnamed: U4.2 (XOUT), Y1.3
unnamed: R17.2, U4.17 (~XRSTJ)
unnamed: TP27.1 (1_1), U5.6 (BOOT_CFG)
unnamed: TP2.1 (1_1), U5.22 (DEBUG_RXD)
unnamed: TP1.1 (1_1), U5.23 (DEBUG_TXD)
unnamed: R21.2, U5.53 (GNSS_ANT)
unnamed: TP7.1, U5.19 (GPIO1/SPI_MOSI)
unnamed: TP8.1, U5.20 (GPIO2/SPI_MISO)
unnamed: TP9.1, U5.21 (GPIO3/SPI_CLK)
unnamed: TP10.1, U5.34 (GPIO4)
unnamed: TP11.1, U5.48 (GPIO5/SPI_CS)
unnamed: TP12.1, U5.67 (GPIO6)
unnamed: TP13.1, U5.68 (GPIO7)
unnamed: TP30.1 (1_1), U5.38 (I2C_SCL)
unnamed: TP29.1 (1_1), U5.37 (I2C_SDA)
unnamed: R20.2, U5.1 (PWRKEY)
unnamed: R22.2, U5.60 (RF_ANT)
unnamed: TP3.1, U5.49 (UART3_RXD)
unnamed: TP4.1, U5.50 (UART3_TXD)
unnamed: TP25.1 (1_1), U5.28 (USB_DM)
unnamed: TP26.1 (1_1), U5.27 (USB_DP)
unnamed: TP24.1 (1_1), U5.24 (USB_VBUS)
unnamed: R57.2, U6.15 (IO6)
unnamed: R58.1, U6.20 (IO15)
unnamed: TP21.1, U6.27 (IO21)
unnamed: TP22.1, U6.28 (IO22)
unnamed: TP23.1, U6.29 (IO23)
unnamed: Q3.2, U7.15 (HIDRV)
unnamed: Q4.2, U7.13 (LODRV)
unnamed: C45.2, L1.1, Q3.3, Q4.1, U7.14 (PH)
unnamed: C51.1, L1.2, R66.1, U7.10 (SRP)
unnamed: R70.2, U7.4 (TS)
unnamed: C43.2, R53.2, U7.1 (VCC)
unnamed: C52.2, R67.1, R68.2, U7.8 (VFB)
unnamed: R23.1, SW3.2, U15.7 (EN)
unnamed: R8.1, U15.1 (FB/VSET)
unnamed: R15.1, U15.8 (MODE/S-CONF)
unnamed: R33.2, U15.2 (PG)
unnamed: L2.1, U15.4 (SW)
unnamed: C9.2, R9.2, R11.1, VR3.7 (FB)
PSIM_VCC: C36.1, C37.1, D6.4 (TVS3), J4.1, J6.C1 (VCC)
RF_ANT: C31.1, R22.1, R39.1
RPI_PWR_EN: PS1.1 (EN), R35.1, U6.19 (IO14)
RPI_SCL: R13.2, U2.5 (GPIO3/SCL), U3.15 (SDA)
RPI_SDA: R14.2, U2.3 (GPIO2/SDA), U3.14 (SCL)
SIM_CLK: C39.1, J8.1, R52.1
SIM_DATA: C40.1, J7.1, R59.1
SIM_PWRKEY: Q6.3 (C2), R20.1
SIM_PWRKEY_Rpi: R72.1, U2.11 (GPIO17/GEN0)
SIM_PWR_EN: R10.1, R58.2, U2.13 (GPIO27/GEN2), VR3.6 (EN)
SIM_RST: C38.1, J5.1, R40.1
SIM_VCC: C11.1, C12.1, C13.1, C14.1, C15.1, C16.1, D1.2 (A), D2.2 (A), FB2.1, U5.55 (VBAT), U5.56 (VBAT), U5.57 (VBAT)
SIM_VCC_FB: C9.1, C10.1, FB2.2, R9.1, VR3.3 (VOUT)
STATUS: R29.1, U5.66 (STATUS)
VDD_EXT: Q8.1 (G), Q9.1 (G), R78.2, R81.2, TP28.1 (1_1), U5.15 (VDD_EXT)
VIN: C64.1, D3.2 (A), J13.2, R54.1, R62.1, TP14.1 (1_1)

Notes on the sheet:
GPIO9
SIGNALS (ESP - RPI - SIM)
PULL UP (1)
GSM ANTENNA CONNECTOR
SIM MODULE SMPM
GNSS ANTENNA CONNECTOR
BOOT MODE CONTROL
Solar cell
ESP32-C6-MINI-1
SOLAR CHARGE CONTROLLER
RPi REG
RED
I2C PULL-UP
RST PULL-UP
SIM MODULE
BATTERY MONITORING
SIM MODULE RESET / PWR KEY
*Active Low
SIM MODULE NETWORK LED
Humadity + Temp Sensor
Battery Pack
RASPBERRY PI ZERO W
USB HUB RPI CAMERA
SPI BOOT (Default)
PULL DWN (0)
FLOATING (-)
GPIO8
BOOT MODE
GREEN
SIM MODULE STATUS LED
Thermister
MAIN / ESP REG
USIM SOCKET
Download Boot
ESIM SOCKET
ESP PROGRAMMING
10K 3.6k

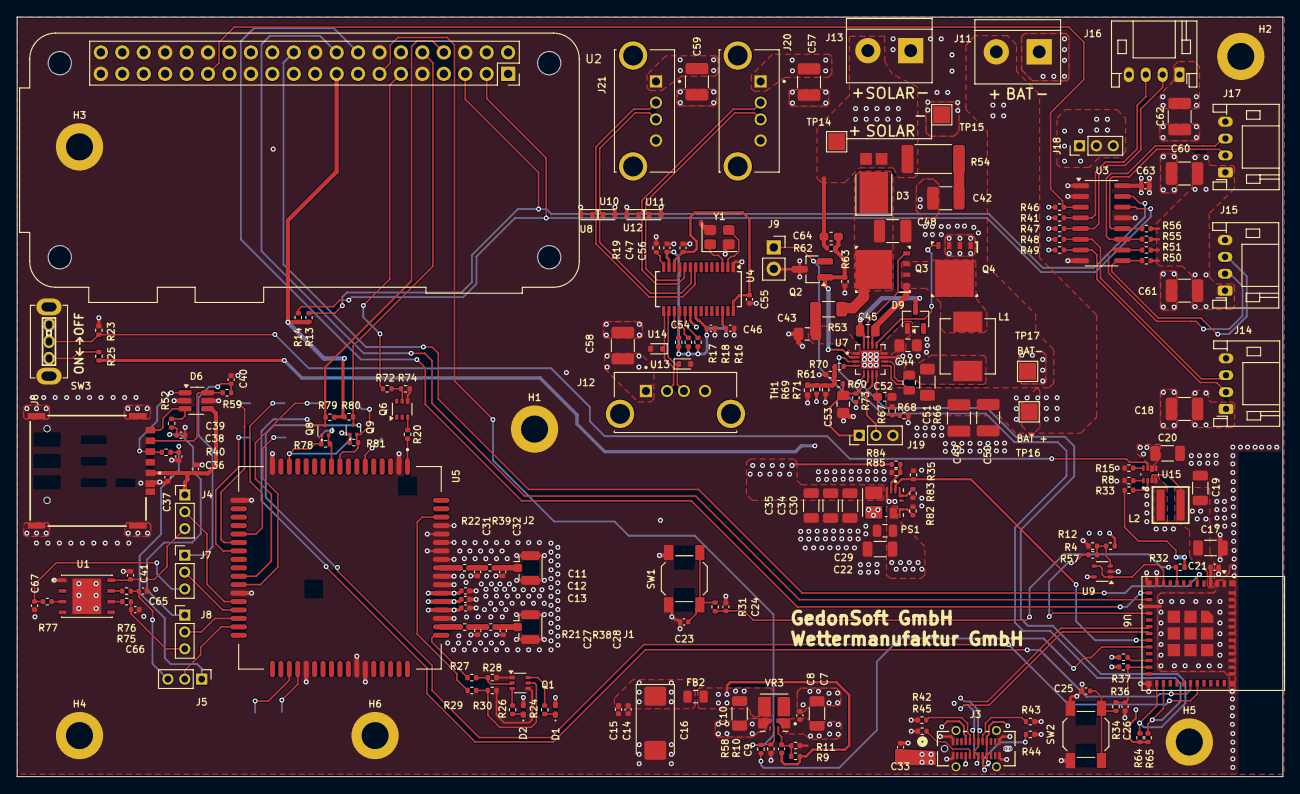
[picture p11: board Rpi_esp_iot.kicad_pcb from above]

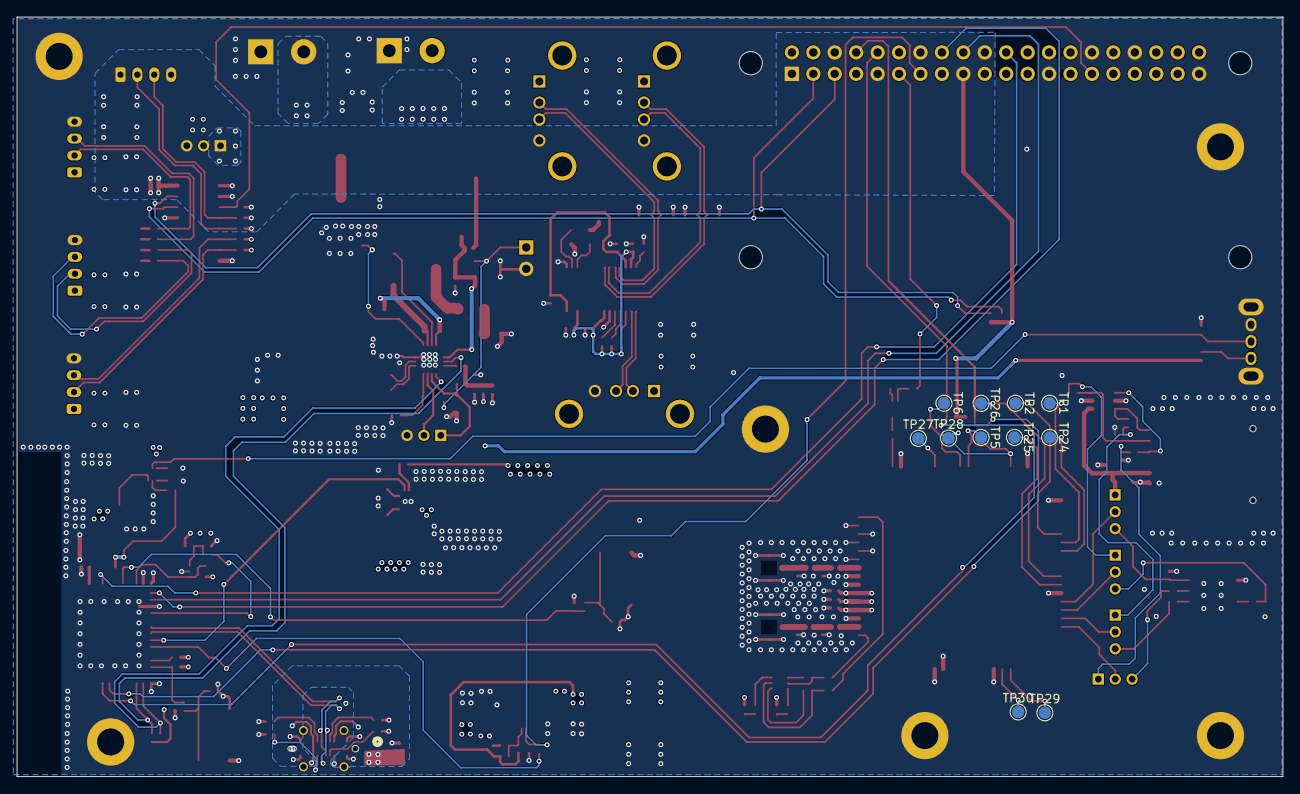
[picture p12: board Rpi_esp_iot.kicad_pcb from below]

Board: 4 copper layers, 150.0 x 90.0 mm, 218 parts (11 on the bottom side), 132 nets.

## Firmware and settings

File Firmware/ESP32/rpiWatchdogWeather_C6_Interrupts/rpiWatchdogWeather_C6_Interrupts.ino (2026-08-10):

#include <WiFi.h>
#include <WebServer.h>
#include <Preferences.h>
#include "esp_sleep.h"
#include "esp_task_wdt.h"

#define IMAGE_SENT_SIGNAL_FROM_RPI          0   // GPIO23 on RPi
#define SEND_SHUTDOWN_SIGNAL_TO_RPI         1   // GPIO24 on RPi
#define SHUTDOWN_COMPLETE_STATUS_FROM_RPI   2   // GPIO25 on RPi
#define BATTERY_PIN                         5   // Battery monitoring pin
#define RPI_ENABLE                          14  // To enable power for RPi
 
const char* apSSID = "ESP32-CAMERA-CONFIG";
const char* apPassword = "12345678";

bool          checkPiStatus     = false;
bool          configMode        = false;
volatile bool imageSentFlag     = false;
static float  Vbat              = 0.0;
unsigned long PiStartTime       = 0;
unsigned long shutdownStart     = 0;
unsigned long configStartMillis = 0;
RTC_DATA_ATTR bool skipConfigPortal = false;    // should be false



const uint32_t PI_TIMEOUT              = 8UL  * 60 * 1000;       // 8 mins    
const uint32_t WDT_TIMEOUT             = 2UL  * 60 * 1000;       // 2 mins      
const uint32_t CONFIG_TIMEOUT_MS       = 3UL  * 60 * 1000;      // 3 mins
const uint32_t SHUTDOWN_TIMEOUT        = 3UL  * 60 * 1000;      // 3 mins 
const uint64_t SLEEP_TIME_BATTERY_DIE  = 60UL * 60 * 1000000;   // 60 mins  
uint64_t       SLEEP_TIME              = 20UL * 60 * 1000000;   // 20 mins, will also be fetched by webserver of esp and will be initilaised in function startNormalMode
uint8_t        PI_RESTARTS             = 0;

// Global Config Values
String cameraId, location, ftpHost, ftpUser, ftpPass, ftpPath = "/", protocol = "ftp";
uint32_t ftpPort = 21;
uint32_t frameRate = 20;    // 20 mins
uint32_t newFrameRate = 20;  // getting it from server (RPi)

WebServer server(80);
Preferences prefs;

void shutdownAndSleep(String reason);
void checkPiTimeout();
float readBatteryRaw();

void IRAM_ATTR imageSentISR() 
{
  imageSentFlag = true;
}

esp_task_wdt_config_t wdtConfig = 
{
  .timeout_ms = WDT_TIMEOUT, 
  .trigger_panic = true,
};

bool isConfigured() 
{
  return prefs.getBool("configured", false);
}

void loadConfig() 
{
  cameraId = prefs.getString("cameraId", "");
  location = prefs.getString("location", "");
  ftpHost  = prefs.getString("ftpHost", "");
  ftpPort  = prefs.getUInt("ftpPort", 21);
  ftpUser  = prefs.getString("ftpUser", "");
  ftpPass  = prefs.getString("ftpPass", "");
  ftpPath  = prefs.getString("ftpPath", "/");
  protocol = prefs.getString("protocol", "ftp");
  frameRate = prefs.getUInt("frameRate", 20);
}

void stopConfigPortal() 
{
  server.stop();
  WiFi.softAPdisconnect(true);
  WiFi.mode(WIFI_OFF);
  configMode = false;
  Serial.println("Configuration mode stopped.");
}

void handleRoot() 
{
  String cameraId = prefs.getString("cameraId", "");
  String location = prefs.getString("location", "");
  String ftpHost  = prefs.getString("ftpHost", "");
  String ftpUser  = prefs.getString("ftpUser", "");
  String ftpPath  = prefs.getString("ftpPath", "/");
  String protocol = prefs.getString("protocol", "ftp");
  uint32_t ftpPort = prefs.getUInt("ftpPort", 21);
  uint32_t frameRate = prefs.getUInt("frameRate", 20);
  
  String page = R"rawliteral(
<!DOCTYPE html>
<html>
<head>
  <meta name="viewport" content="width=device-width, initial-scale=1">
  <title>ESP32 Camera Config</title>
</head>
<body>
  <h2>Camera Configuration</h2>
  <form method="POST" action="/save">
    Camera ID:<br>
    <input name="cameraId" value="%CAMERA_ID%" required><br><br>

    Location:<br>
    <input name="location" value="%LOCATION%"><br><br>

    FTP Host:<br>
    <input name="ftpHost" value="%FTP_HOST%" required><br><br>

    FTP Port:<br>
    <input name="ftpPort" type="number" value="%FTP_PORT%" required><br><br>

    Protocol:<br>
    <select name="protocol" required>
      <option value="ftp" %FTP_SELECTED%>FTP</option>
      <option value="sftp" %SFTP_SELECTED%>SFTP</option>
    </select><br><br>


    FTP Username:<br>
    <input name="ftpUser" value="%FTP_USER%"><br><br>

    FTP Password:<br>
    <input name="ftpPass" type="password" placeholder="Leave blank to keep current password"><br><br>

    FTP Path:<br>
    <input name="ftpPath" value="%FTP_PATH%"><br><br>

    Image Sending Frequency (mins): <br>
    <input name="frameRate" value="%FRAME_RATE%"><br><br>
    
    <button type="submit">Save</button>
  </form>
</body>
</html>
)rawliteral";

  page.replace("%CAMERA_ID%", cameraId);
  page.replace("%LOCATION%", location);
  page.replace("%FTP_HOST%", ftpHost);
  page.replace("%FTP_PORT%", String(ftpPort));
  page.replace("%FTP_USER%", ftpUser);
  page.replace("%FTP_PATH%", ftpPath);
  page.replace("%FTP_SELECTED%", protocol == "ftp" ? "selected" : "");
  page.replace("%SFTP_SELECTED%", protocol == "sftp" ? "selected" : "");
  page.replace("%FRAME_RATE%", String(frameRate));
  
  server.send(200, "text/html", page);
}

void handleSave() 
{
  String newCameraId = server.arg("cameraId");
  String newLocation = server.arg("location");
  String newFtpHost  = server.arg("ftpHost");
  String newFtpPort  = server.arg("ftpPort");
  String newFtpUser  = server.arg("ftpUser");
  String newFtpPass  = server.arg("ftpPass");
  String newFtpPath  = server.arg("ftpPath");
  String newProtocol = server.arg("protocol");
  String newFrameRate = server.arg("frameRate");

  newCameraId.trim();
  newLocation.trim();
  newFtpHost.trim();
  newFtpPort.trim();
  newFtpUser.trim();
  newFtpPass.trim();
  newFtpPath.trim();
  newFrameRate.trim();
  newProtocol.trim();
  newProtocol.toLowerCase();

  if (newCameraId.length() == 0 || newFtpHost.length() == 0 || newFtpPort.length() == 0) 
  {
    server.send(400, "text/html", "<h2>Camera ID, FTP Host and FTP Port are required.</h2>");
    return;
  }

  int newPort = newFtpPort.toInt();
  if (newPort <= 0 || newPort > 65535) 
  {
    server.send(400, "text/html", "<h2>Invalid FTP port.</h2>");
    return;
  }

  if (newFtpPath.length() == 0) 
  {
    newFtpPath = "/";
  }

  if (newProtocol != "ftp" && newProtocol != "sftp")
  {
    server.send(400, "text/html", "<h2>Protocol must be ftp or sftp.</h2>");
    return;
  }


  prefs.putString("cameraId", newCameraId);
  prefs.putString("location", newLocation);
  prefs.putString("ftpHost", newFtpHost);
  prefs.putUInt("ftpPort", newPort);
  prefs.putString("ftpUser", newFtpUser);
  prefs.putString("ftpPath", newFtpPath);
  prefs.putString("protocol", newProtocol);

  if (newFtpPass.length() > 0) 
  {
    prefs.putString("ftpPass", newFtpPass);
  }

  if (newFrameRate.toInt() <= 0 || newFrameRate.toInt() > 1440)
  {
    server.send(400, "text/html", "<h2>Frame rate must be 1..1440 minutes.</h2>");
    return;
  }
  prefs.putUInt("frameRate", newFrameRate.toInt());
  
  prefs.putBool("configured", true);
  prefs.putBool("configChanged", true);

  loadConfig();

  server.send(200, "text/html", "<h2>Configuration saved.</h2><p>Using new configuration.</p>");
  delay(1000);

  stopConfigPortal();
}

void startConfigPortal() 
{
  WiFi.mode(WIFI_AP);
  WiFi.softAP(apSSID, apPassword, 1, false, 1); // only 1 client connection

  Serial.println("Configuration mode started");
  Serial.print("Open: http://");
  Serial.println(WiFi.softAPIP());

  server.on("/", HTTP_GET, handleRoot);
  server.on("/save", HTTP_POST, handleSave);
  server.begin();

  configMode = true;
  configStartMillis = millis();
}

void startNormalMode() 
{
  if (!isConfigured()) 
  {
    Serial.println("No valid configuration. Normal mode not started.");
    return;
  }

  loadConfig();
  SLEEP_TIME = (uint64_t)frameRate * 60 * 1000000; // FrameRate in milliseconds

  Serial.println("Normal mode started");
  Serial.println("Camera ID: " + cameraId);
  Serial.println("Location: " + location);
  Serial.println("FTP Host: " + ftpHost);
  Serial.println("FTP Port: " + String(ftpPort));
  Serial.println("FTP User: " + ftpUser);
  Serial.println("FTP Path: " + ftpPath);
  Serial.println("FTP Password length: " + String(ftpPass.length()));
  Serial.println("Protocol: " + protocol);
  Serial.println("Frame Rate: " + String(frameRate));
}

void setup() 
{
  Serial.begin(115200);
  Serial0.begin(9600);
  
  pinMode(IMAGE_SENT_SIGNAL_FROM_RPI, INPUT_PULLDOWN);
  pinMode(SEND_SHUTDOWN_SIGNAL_TO_RPI, OUTPUT);
  pinMode(SHUTDOWN_COMPLETE_STATUS_FROM_RPI, INPUT_PULLDOWN);
  pinMode(RPI_ENABLE, OUTPUT);
  
  analogReadResolution(12);
  delay(1000);
  float raw = readBatteryRaw();
  Vbat = (0.006161 * raw) - 6.11;
  Serial.print("Raw = "); Serial.println(raw);
  Serial.print("Battery Voltage = "); Serial.println(Vbat);

  if (Vbat < 9.6)
  {
    Serial.println("Battery too low, going to sleep...");
    esp_sleep_enable_timer_wakeup(SLEEP_TIME_BATTERY_DIE);
    esp_deep_sleep_start();
  }

  prefs.begin("cam-config", false);
  if (!skipConfigPortal)
  {
    startConfigPortal();
    while (configMode)
    {
      server.handleClient();
      if (millis() - configStartMillis >= CONFIG_TIMEOUT_MS)
      {
        Serial.println("Configuration timeout reached");
        stopConfigPortal();
      }
      delay(1);
    }
  }
  else
  {
    Serial.println("Skipping config portal after deep sleep");
  }
  startNormalMode();

  digitalWrite(RPI_ENABLE, LOW);
  delay(2000);
  digitalWrite(RPI_ENABLE, HIGH);

  esp_task_wdt_deinit();
  esp_task_wdt_init(&wdtConfig);
  esp_task_wdt_add(NULL);

  PiStartTime = millis();
  attachInterrupt(digitalPinToInterrupt(IMAGE_SENT_SIGNAL_FROM_RPI), imageSentISR, RISING);
}

void loop() 
{
  esp_task_wdt_reset();
  checkPiTimeout();
  
  if (digitalRead(SHUTDOWN_COMPLETE_STATUS_FROM_RPI) == HIGH)
  {
    checkPiStatus = true;
  }
  
  if (checkPiStatus && (digitalRead(SHUTDOWN_COMPLETE_STATUS_FROM_RPI) == LOW ))
  {
    shutdownAndSleep("Error/Exception occured at RPi side");
  }

  if(Serial0.available())
  {
    esp_task_wdt_reset();
    PiStartTime = millis();           // Resetting Pi Timeout

    String cmd = Serial0.readStringUntil('\n');
    cmd.trim();

    if (cmd == "SEND VOLTAGE")
    {
      Serial.println("Sending Voltage");
      Serial0.println(Vbat);
    }

    if (cmd == "SEND CONFIG")
    {
      loadConfig();
      if (prefs.getBool("configChanged", false))        // checking for configChanged variable, if it doesn't exist mark it as false
      {
        Serial.println("Sending Config");
        Serial0.print(cameraId); Serial0.print("|");
        Serial0.print(location); Serial0.print("|");
        Serial0.print(ftpHost);  Serial0.print("|");
        Serial0.print(ftpPort);  Serial0.print("|");
        Serial0.print(ftpUser);  Serial0.print("|");
        Serial0.print(ftpPass);  Serial0.print("|");
        Serial0.print(ftpPath);  Serial0.print("|");
        Serial0.print(protocol); Serial0.print("|");
        Serial0.println(frameRate);
      }
      else
      {
        Serial.println("No new config");
        Serial0.println("NO NEW CONFIG");
      }
    }

    if (cmd == "CONFIG SAVED")
    {
      Serial.println("Configurations Saved in RPi");
      prefs.putBool("configChanged", false);            // marking it false again, so esp knows that configurations are not changed on next run
    }

    if (cmd.startsWith("SET FRAMERATE"))
    {
      newFrameRate = cmd.substring(14).toInt();
      if (newFrameRate > 0 && newFrameRate!= frameRate)
      {
        frameRate = newFrameRate;
        prefs.putUInt("frameRate", newFrameRate);
        SLEEP_TIME = (uint64_t) newFrameRate * 60 * 1000000;
        Serial0.println("FRAMERATE UPDATED");

        Serial.print("Frame Rate updated to (mins): "); Serial.println(newFrameRate);
        
      }
      else if (newFrameRate == frameRate)
      {
        Serial0.println("FRAMERATE IDENTICAL TO SAVED FRAME RATE");
        Serial.println("Same Frame Rate");
      }
      else
      {
        Serial0.println("FRAMERATE INVALID");
        Serial.print("Invalid frame rate received");
      }
    }
  }

  if(imageSentFlag) 
  {
    Serial.println("Interrupt Detected");
    esp_task_wdt_reset();

    imageSentFlag = false;
    PiStartTime = millis();

    Serial.println("Image Sent to server! Sending shutdown command to Pi.");
    digitalWrite(SEND_SHUTDOWN_SIGNAL_TO_RPI, HIGH);
    shutdownAndSleep("Image Successfully Sent");
  }
}












// --- Wait for RPi shutdown confirmation, then power off and sleep ---
void shutdownAndSleep(String reason)
{
  shutdownStart = millis();
  unsigned long lowSince = 0;

  while (true)
  {
    esp_task_wdt_reset();
    int pin = digitalRead(SHUTDOWN_COMPLETE_STATUS_FROM_RPI);

    if (pin == LOW)
    {
      if (lowSince == 0)
      {
        lowSince = millis();
      }
      if (millis() - lowSince >= 200)
      {
        break;
      }
    }
    else
    {
      lowSince = 0;
    }

    if (millis() - shutdownStart > SHUTDOWN_TIMEOUT)
    {
      Serial.println("Pi shutdown timeout, forcing power off.");
      break;
    }
    delay(10);
  }

  Serial.print("Pi shutdown down:");  Serial.println(reason);
  digitalWrite(SEND_SHUTDOWN_SIGNAL_TO_RPI, LOW);
  delay(500);

  digitalWrite(RPI_ENABLE, LOW);
  delay(500);

  skipConfigPortal = true;
  Serial.print("ESP going to deep sleep for ");
  Serial.println(SLEEP_TIME);
  delay(1000);
  esp_sleep_enable_timer_wakeup(SLEEP_TIME);
  esp_deep_sleep_start();
}











// --- Check Pi timeout ---
void checkPiTimeout() 
{
  if (millis() - PiStartTime > PI_TIMEOUT) 
  { 
    PI_RESTARTS++;
    Serial.println("Pi timeout! Power cycling...");
    digitalWrite(RPI_ENABLE, LOW);
    delay(2000);
    digitalWrite(RPI_ENABLE, HIGH);
    delay(2000);
    PiStartTime = millis();

    if (PI_RESTARTS >= 2)
    {
      Serial.println("Pi failed after max restarts. Forcing sleep.");
      shutdownAndSleep("Pi max restarts done");
    }
  }
}


float readBatteryRaw() 
{
  long total = 0;
  const int samples = 100;

  for (int i = 0; i < samples; i++) {
    total += analogRead(BATTERY_PIN);
    delay(2);
  }

  return total / (float)samples;
}

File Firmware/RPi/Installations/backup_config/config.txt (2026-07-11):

# For more options and information see
# http://rptl.io/configtxt
# Some settings may impact device functionality. See link above for details

# Uncomment some or all of these to enable the optional hardware interfaces
dtparam=i2c_arm=on
#dtparam=i2s=on
#dtparam=spi=on

# Enable audio (loads snd_bcm2835)
dtparam=audio=on

# Additional overlays and parameters are documented
# /boot/firmware/overlays/README

# Automatically load overlays for detected cameras
camera_auto_detect=1

# Automatically load overlays for detected DSI displays
display_auto_detect=1

# Automatically load initramfs files, if found
auto_initramfs=1

# Enable DRM VC4 V3D driver
dtoverlay=vc4-kms-v3d
max_framebuffers=2

# Don't have the firmware create an initial video= setting in cmdline.txt.
# Use the kernel's default instead.
disable_fw_kms_setup=1

# Run in 64-bit mode
arm_64bit=1

# Disable compensation for displays with overscan
disable_overscan=1

# Run as fast as firmware / board allows
arm_boost=1

[cm4]
# Enable host mode on the 2711 built-in XHCI USB controller.
# This line should be removed if the legacy DWC2 controller is required
# (e.g. for USB device mode) or if USB support is not required.
otg_mode=1

[cm5]
dtoverlay=dwc2,dr_mode=host

[all]
dtoverlay=legacy-gpio
dtoverlay=w1-gpio

dtoverlay=disable-bt
enable_uart=1
hdmi_blanking=2

dt_overlay = uart1, txd1_pin=12, rxd1_pin=13

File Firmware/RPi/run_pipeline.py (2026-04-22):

#!/usr/bin/env python3
import argparse
import json
from pathlib import Path
from typing import Dict, List, Tuple, Optional

import numpy as np
from PIL import Image, ImageDraw, ImageFilter
import onnxruntime as ort


# ---------- Helpers ----------

def np_softmax(logits: np.ndarray, axis: int = -1) -> np.ndarray:
    logits = logits - logits.max(axis=axis, keepdims=True)
    e = np.exp(logits)
    return e / e.sum(axis=axis, keepdims=True)


def np_sigmoid(x: np.ndarray) -> np.ndarray:
    return 1.0 / (1.0 + np.exp(-x))


def paste_black_rects(pil_img: Image.Image, boxes: np.ndarray) -> Image.Image:
    # Erwartet YOLOX-Boxen im Format (top, left, bottom, right)
    out = pil_img.copy()
    drw = ImageDraw.Draw(out)
    W, H = out.size
    for b in boxes:
        top, left, bottom, right = map(float, b)
        l = int(max(0, min(left, right)))
        r = int(min(W, max(left, right)))
        t = int(max(0, min(top, bottom)))
        bt = int(min(H, max(top, bottom)))
        if l >= r or t >= bt:
            continue
        drw.rectangle([l, t, r, bt], fill=(0, 0, 0))
    return out


def blur_heads_elliptical(
    image: Image.Image,
    boxes: np.ndarray,
    padding_factor: float = 0.10,
    blur_factor: float = 15.0,
) -> Image.Image:
    # Erwartet Boxen im Format [x1, y1, x2, y2]
    result_image = image.copy()
    mask = Image.new('L', image.size, 0)
    draw = ImageDraw.Draw(mask)

    for box in boxes:
        x1, y1, x2, y2 = map(float, box)
        width = x2 - x1
        height = y2 - y1
        if width <= 0 or height <= 0:
            continue

        pad_w = padding_factor * width
        pad_h = padding_factor * height

        x1n = max(0.0, x1 - pad_w)
        y1n = max(0.0, y1 - pad_h)
        x2n = min(image.width, x2 + pad_w)
        y2n = min(image.height, y2 + pad_h)

        l, t, r, b = map(int, [x1n, y1n, x2n, y2n])
        if l >= r or t >= b:
            continue
        draw.ellipse([l, t, r, b], fill=255)

    blurred = image.filter(ImageFilter.GaussianBlur(radius=blur_factor))
    result_image = Image.composite(blurred, image, mask)
    return result_image


def parse_size_arg(s: Optional[str]) -> Optional[Tuple[int, int]]:
    if s is None:
        return None
    if 'x' in s:
        parts = s.lower().split('x')
    elif ',' in s:
        parts = s.split(',')
    else:
        raise argparse.ArgumentTypeError("output-size must be in format WIDTHxHEIGHT (z.B. 1280x720)")
    if len(parts) != 2:
        raise argparse.ArgumentTypeError("output-size must be in format WIDTHxHEIGHT (z.B. 1280x720)")
    try:
        w = int(parts[0])
        h = int(parts[1])
    except ValueError:
        raise argparse.ArgumentTypeError("output-size values must be integers")
    if w <= 0 or h <= 0:
        raise argparse.ArgumentTypeError("output-size values must be positive")
    return (w, h)


def scale_boxes(
    boxes: np.ndarray,
    from_size: Tuple[int, int],
    to_size: Tuple[int, int],
    fmt: str = "yolox",
) -> np.ndarray:
    """
    Scale boxes from from_size (width, height) to to_size (width, height).
    fmt:
      - "yolox": boxes in (top, left, bottom, right) -> scale y by scale_y, x by scale_x
      - "head": boxes in (x1, y1, x2, y2) -> scale x by scale_x, y by scale_y
    """
    if boxes is None or boxes.size == 0:
        return boxes.copy() if isinstance(boxes, np.ndarray) else np.empty((0, 4), dtype=np.float32)
    from_w, from_h = from_size
    to_w, to_h = to_size
    if from_w == 0 or from_h == 0:
        raise ValueError("from_size must be non-zero")
    sx = to_w / float(from_w)
    sy = to_h / float(from_h)
    boxes = np.array(boxes, dtype=np.float32)
    scaled = boxes.copy()
    if fmt == "yolox":
        # (top, left, bottom, right)
        scaled[:, 0] = boxes[:, 0] * sy  # top -> y
        scaled[:, 1] = boxes[:, 1] * sx  # left -> x
        scaled[:, 2] = boxes[:, 2] * sy  # bottom -> y
        scaled[:, 3] = boxes[:, 3] * sx  # right -> x
    elif fmt == "head":
        # (x1, y1, x2, y2)
        scaled[:, 0] = boxes[:, 0] * sx
        scaled[:, 1] = boxes[:, 1] * sy
        scaled[:, 2] = boxes[:, 2] * sx
        scaled[:, 3] = boxes[:, 3] * sy
    else:
        raise ValueError("Unknown fmt for scale_boxes")
    return scaled


# ---------- Weather (multilabel optional) ----------

class WeatherInfer:
    def __init__(
        self,
        onnx_path: Path,
        classes_path: Optional[Path],
        img_size: int = 136,
        use_gpu: bool = False,
        multilabel: bool = False,
    ):
        self.img_size = img_size
        self.multilabel = multilabel

        # Klassen-Mapping optional
        self.idx_to_class: Dict[int, str] = {}
        if classes_path and classes_path.exists():
            with classes_path.open("r", encoding="utf-8") as f:
                class_to_idx = json.load(f)
            self.idx_to_class = {v: k for k, v in class_to_idx.items()}

        providers = ["CPUExecutionProvider"]
        if use_gpu and "CUDAExecutionProvider" in ort.get_available_providers():
            providers = ["CUDAExecutionProvider", "CPUExecutionProvider"]

        so = ort.SessionOptions()
        so.graph_optimization_level = ort.GraphOptimizationLevel.ORT_ENABLE_BASIC
        so.intra_op_num_threads = 1
        so.inter_op_num_threads = 1
        so.execution_mode = ort.ExecutionMode.ORT_SEQUENTIAL
        so.enable_mem_pattern = False
        so.enable_cpu_mem_arena = True
        self.sess = ort.InferenceSession(str(onnx_path), sess_options=so, providers=providers)

        self.MEAN = np.array([0.485, 0.456, 0.406], dtype=np.float32)
        self.STD = np.array([0.229, 0.224, 0.225], dtype=np.float32)

        # Namen im Modell
        self.input_name = self.sess.get_inputs()[0].name
        self.output_name = self.sess.get_outputs()[0].name  # "logits"

    def _preprocess(self, img: Image.Image) -> np.ndarray:
        img = img.resize((self.img_size, self.img_size), resample=Image.BILINEAR)
        x = np.asarray(img).astype(np.float32) / 255.0  # HWC
        x = (x - self.MEAN) / self.STD
        x = np.transpose(x, (2, 0, 1))  # CHW
        x = np.expand_dims(x, axis=0)  # NCHW
        return x

    def predict_probs(self, img: Image.Image) -> Dict[str, float]:
        x = self._preprocess(img)
        logits = self.sess.run([self.output_name], {self.input_name: x})[0]  # [1, C]
        if self.multilabel:
            probs = np_sigmoid(logits)[0]
        else:
            probs = np_softmax(logits, axis=1)[0]
        if not self.idx_to_class:
            self.idx_to_class = {i: f"idx_{i}" for i in range(len(probs))}
        return {self.idx_to_class[i]: float(probs[i]) for i in range(len(probs))}


# ---------- YOLOX (Kennzeichen) ----------
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

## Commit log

2026-06-08 update esp32 code
2026-06-08 changed the sleep time based on battery
2026-06-29 esp32 code changes
2026-06-29 esp32 code refine
2026-07-11 changed data types for variables
    [Rpi_esp_iot.kicad_pcb]
2026-07-11 script updater for raspberry pi
2026-07-11 config backup files
    [config.txt]
2026-07-14 power consumption reports updated
2026-07-15 removed imports for 2 unused sensors
2026-07-15 Replace ntpdate with chronyc makestep in weather.py
    [weather.py]
2026-07-15 Fix DNS resolution after PPP connection on Bookworm
    [weather.py]
2026-07-15 Fix FTP log upload failure by using separate FTP connection for logs
    [weather.py]
2026-07-15 Re-apply DNS in uploadLogs() to fix name resolution at shutdown time
    [weather.py]
2026-07-15 Fix double FTP log upload and logging timezone
    [weather.py]
2026-07-15 Fix DNS resolution failure before main FTP/HTML uploads
    [weather.py]
2026-07-15 Use resolvectl to set DNS on ppp0 interface robustly
    [weather.py]
2026-07-20 Replace ntpdate with chrony for time sync
    [weather.py]
2026-07-20 Fix logging timestamps by re-initializing after chrony time sync
    [weather.py]
2026-07-21 updater config.txt
    [config.txt]
2026-07-21 update fetch frame rate
2026-07-22 update sim_ppp
    [Rpi_esp_iot.kicad_pcb]
2026-07-27 frame rate
2026-07-27 removed pcb files for a while
    [Rpi_esp_iot.kicad_pcb, Rpi_esp_iot.kicad_sch]
2026-07-27 updated for getting FrameRate and sending to esp
2026-07-27 receving frame rate
2026-07-28 removed dependenci of frame rate, not possible
2026-08-04 moved folder inside
    [config.txt]
2026-08-04 updated esp32 code
2026-08-05 fixed all the potential bugs
    [rpiWatchdogWeather_C6_Interrupts.ino, sim_ppp.py, weather.py]
2026-08-05 added mechanism to update frame rate
2026-08-06 updated mechanism of frame rate
